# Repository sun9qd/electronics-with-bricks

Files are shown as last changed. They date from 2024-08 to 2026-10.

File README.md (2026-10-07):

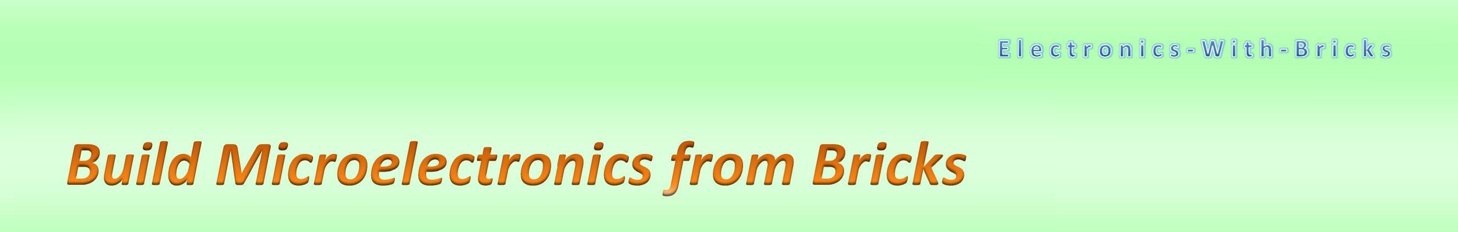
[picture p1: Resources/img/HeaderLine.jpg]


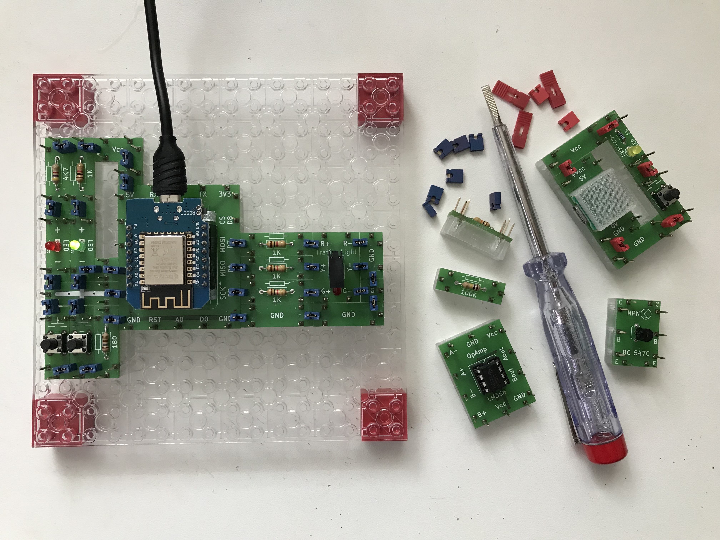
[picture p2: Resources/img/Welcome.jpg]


This project presents an electronic construction kit on 8 mm studded base panel, compatible with standard systems, supporting numerous analog and digital components. From this various analog and digital circuits can be built.

*The latest project built with the construction kit:* A remote-controlled robot car featuring two stacked electronic boards and plenty of space for additional sensor electronics. The picture below shows an assembly with an older brick version.

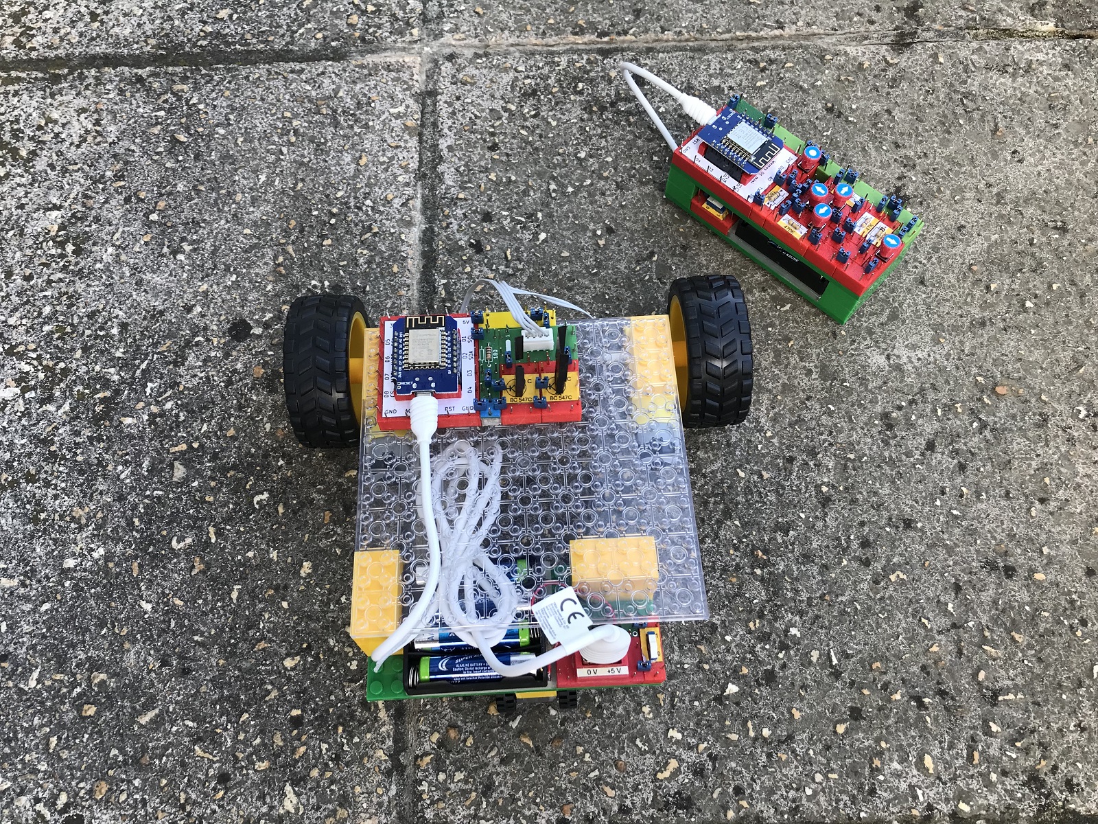
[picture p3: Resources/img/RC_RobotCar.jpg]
Latest project


The kit is intended for:

1. Learning and training
2. Evaluation of electronic components
3. Development of electronic circuits
4. Presentation of technical systems

Compared to using a breadboard, there are some advantages.

1. *Circuit layout  like a photograph of the circuit diagram.*
The wires can be freely routed in two dimensions, whereas on a breadboard, one direction is restricted by the fixed internal wiring. Components and connections are labeled. The tangle of wires is replaced by clearly identifiable jumper connectors.

2. *Robust construction—almost like a manufactured circuit board.*
The components hold firmly to the baseplate, and the jumper connections establish reliable electrical contact. No exposed wires posing a short-circuit risk. 

3. *It’s really fun working with it.*
Finding the best way to lay out the circuit on the base plate. It feels like an amazing, addictive game of skill.

The repository is structured as follows:

- **Applications/** contains a number of experiments built with the kit
- **Bricks/** contains an overview of the available bricks
- **Bundles/** presents several construction kits with varying assortments of building blocks
- **OldApplications/** contains applications with previous version of the kit
- **OldBundles/** contains bundles with previous version of the kit
- **Resources/** contains the resources for reproducing the bricks (STL and Gerber files) and a description how to do that (coming soon)

Note:

LEGO® is a trademark of the LEGO Group. This project is not sponsored, approved or supported by the LEGO Group.

**Warning: The construction kit presented works with electricity. Incorrect use, but also faulty components or circuits, can cause fires and even people and animals can suffer injuries from electric shocks. For this reason, it may only be used by qualified persons. Operation is at your own risk. No liability is assumed for damage resulting from improper assembly or operation.**

The 3D printing templates were created with OpenScad: https://openscad.org/

The board layouts were created with KiCad: https://www.kicad.org/

Some of the description text has been translated with the help of google translator: https://translate.google.com/

Copyright (c) 2024-2026 sun9qd

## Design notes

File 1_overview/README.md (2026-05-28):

# Electronics With Bricks: Sketches

## Laboratory Power Supply

This small circuit provides the voltage of a laboratory power supply to different plugs. The integrated voltmeter displays the current voltage.

The circuit:

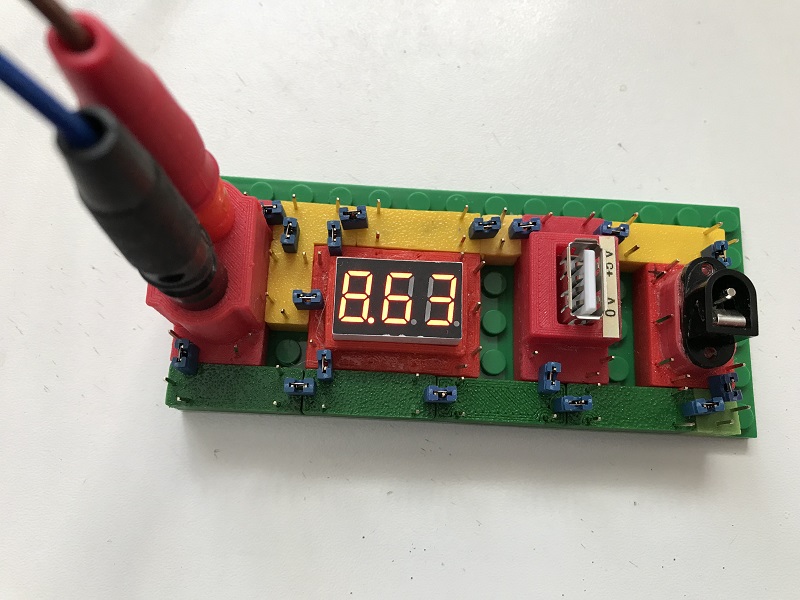
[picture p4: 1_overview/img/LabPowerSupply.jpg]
Lab Power Supply


## Flip-Flop

The most striking thing about the flip-flop circuit or "blinking circuit" are two alternately flashing LEDs that are controlled by two coupled timers. The timing components are a resistor and a capacitor, and there is a transistor as a switch and to drive the LEDs.

The circuit:

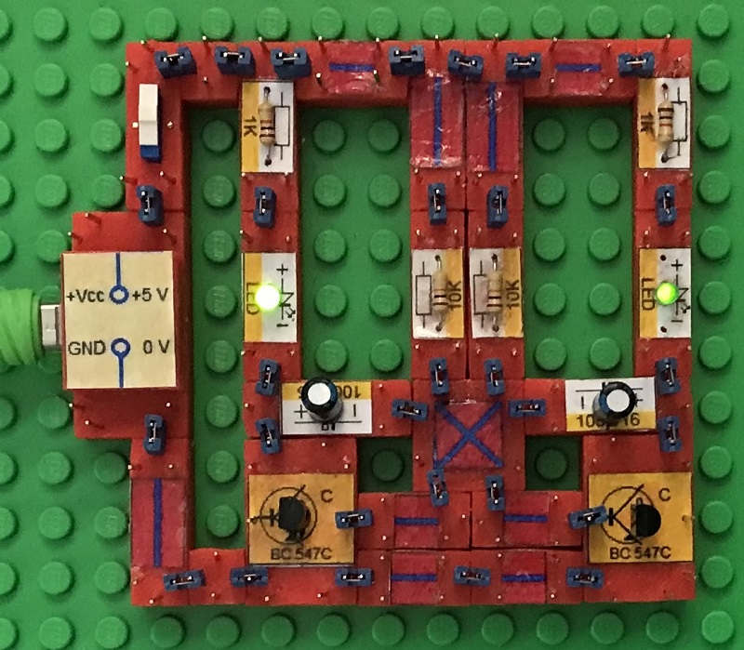
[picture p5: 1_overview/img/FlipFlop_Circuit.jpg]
Flip Flop Circuit


## Analog Water Level Indicator

In this experiment, we build a circuit with which we can measure and display the water level in a water container, e.g. in a water glass or (with a modified sensor) in a rain barrel. The circuit uses analog components in the form of four npn transistors. The water level is displayed using LEDs.

This experiment also shows the use of colored wiring blocks to improve the overview in the circuits. The yellow line blocks are used for the operating voltage, the green ones for the ground line. The latter were not necessary here because the ground line is not switched separately, but is routed via red function blocks.

The circuit:

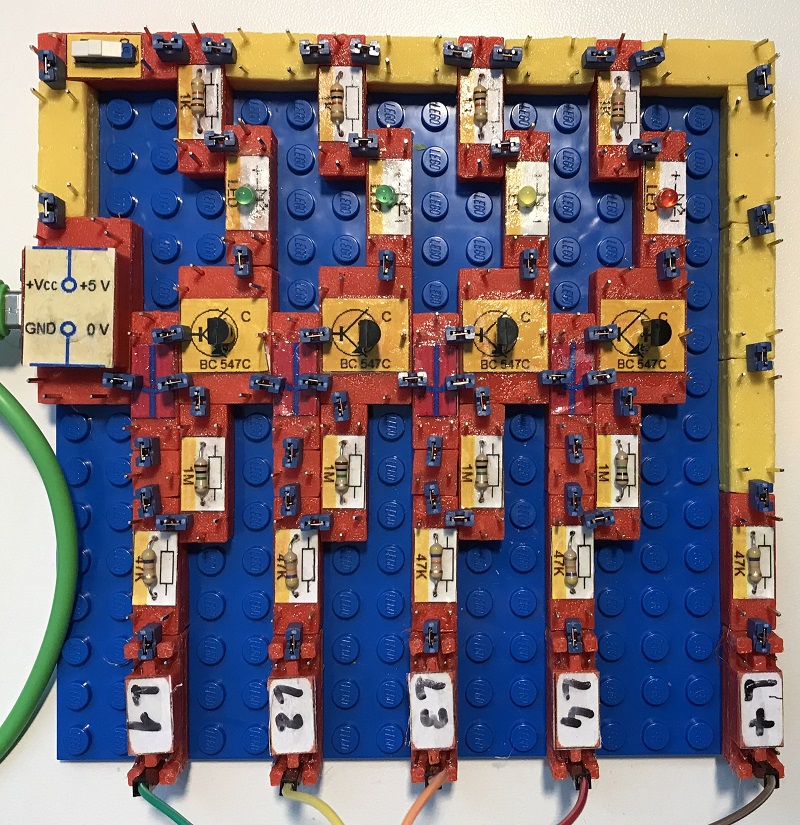
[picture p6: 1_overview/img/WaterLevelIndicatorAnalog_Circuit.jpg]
Water Level Analog Circuit


The entire project, with power supply and sensor:

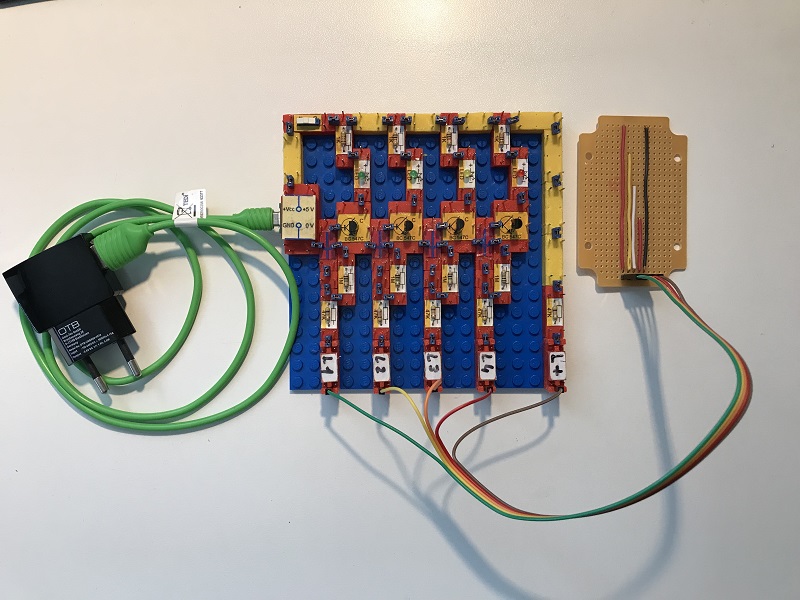
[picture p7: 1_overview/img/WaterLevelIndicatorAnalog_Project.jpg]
Water Level Analog Project


In operation:

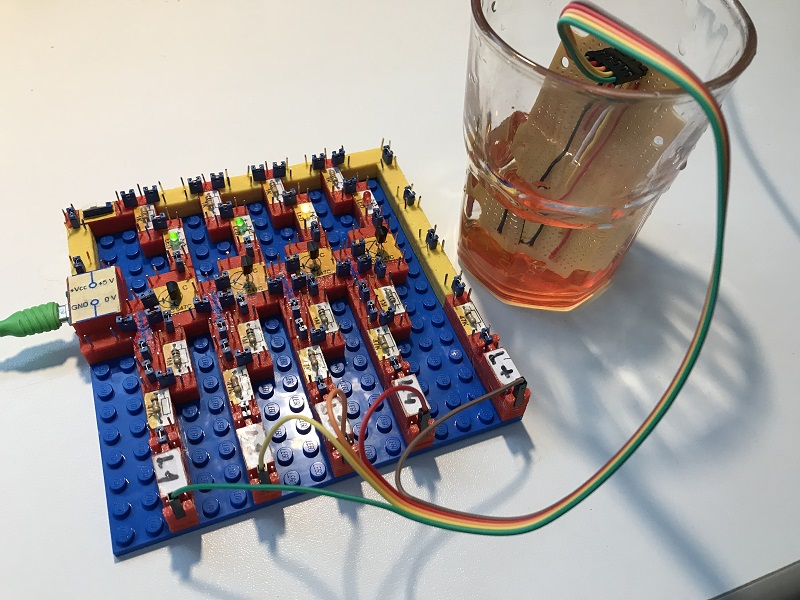
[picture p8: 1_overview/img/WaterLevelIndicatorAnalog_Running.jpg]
Water Level Analog Running


In this experiment, a crossing block is used that makes it possible to cross two lines without them having electrical contact:

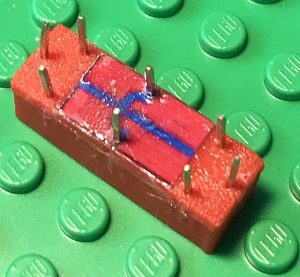
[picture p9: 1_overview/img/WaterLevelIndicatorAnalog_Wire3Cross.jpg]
Crossing block


The crossing block has three pads, with the two outer ones connected to each other inside the block, while the middle one has no connections. In this way, the crossing connection can be switched via the middle pad with its two connectors.

## 7-Segment Display

This experiment is about displaying a single digit, controlled by a Raspberry Pico microcontroller. The microcontroller sends commands via an i2c bus to a port extender chip to set its IO ports so that the desired segments of the display module light up.

The yellow line modules are used for the operating voltage, the green ones for the ground line.

At the top right of the structure you can see a voltmeter module that measures the operating voltage.

The circuit in operation, the controlled display counts up in 1-second steps:

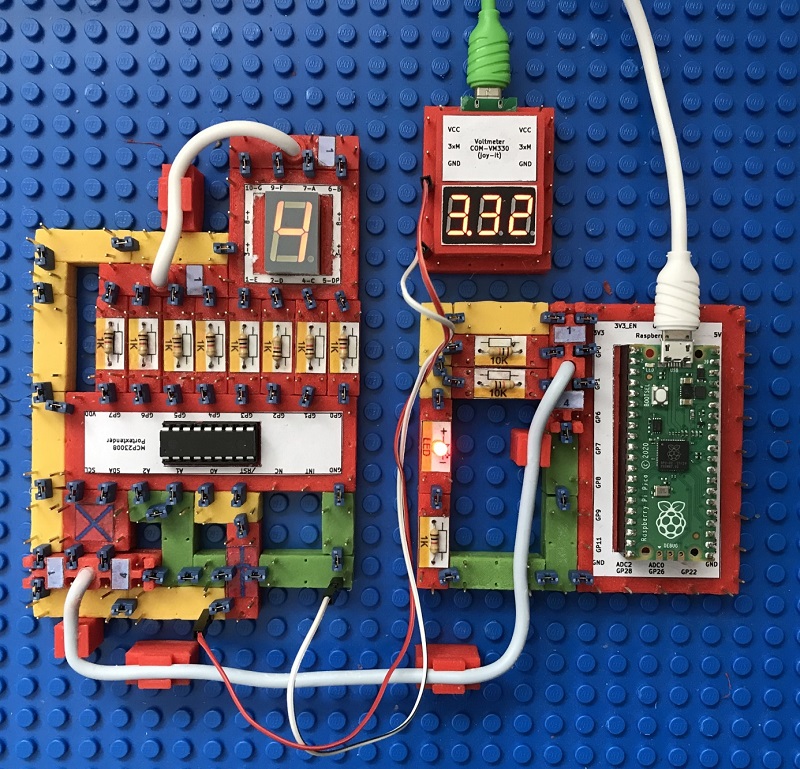
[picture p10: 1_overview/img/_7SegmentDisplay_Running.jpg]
7-Segment Display


In this experiment, a bus line module is used to route Vcc,Ground,SCL and SDA from the microprocessor to the IO extender module. A second of these components redirects the top 4 connections of the display module downwards to the IO extender component.

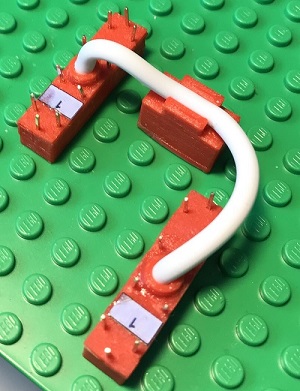
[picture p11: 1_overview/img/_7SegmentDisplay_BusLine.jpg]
7-Segment Busleitung


## Voltmeter

In this experiment we build a voltmeter to measure electrical voltages.

The voltage is measured with an ADC (analog-digital converter) that is built into the D1-Mini microcontroller board.

The measured voltage is displayed on a small graphic display that is connected to the microcontroller via i2c.

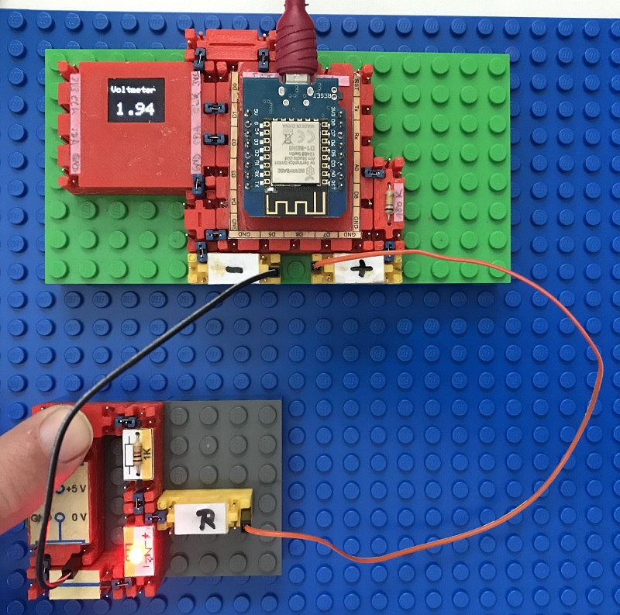
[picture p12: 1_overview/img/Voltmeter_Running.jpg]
Voltmeter


## MP3 Player

In this experiment an integrated MP3 player is used that provides a direct loudspeaker output. The circuit is limited to controlling this component using a series of buttons and connecting a miniature loudspeaker.

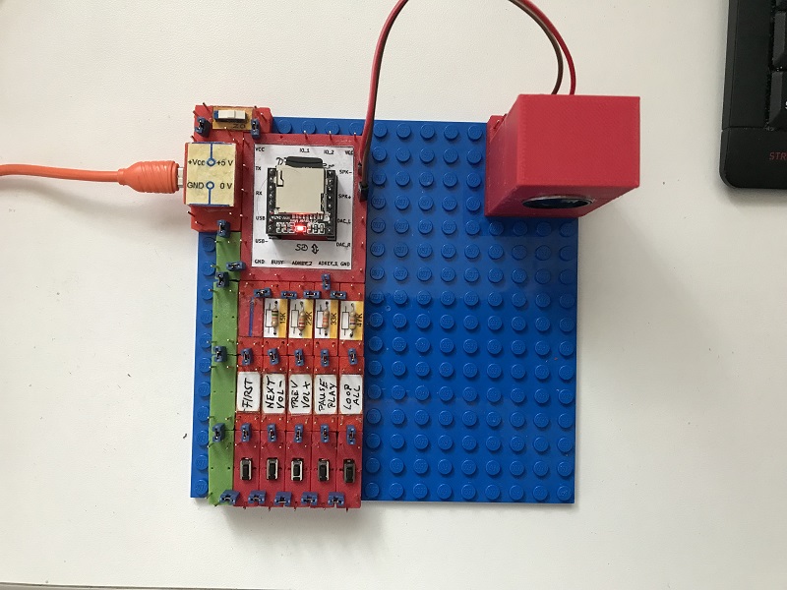
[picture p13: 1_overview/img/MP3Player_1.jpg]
MP3 Player 1


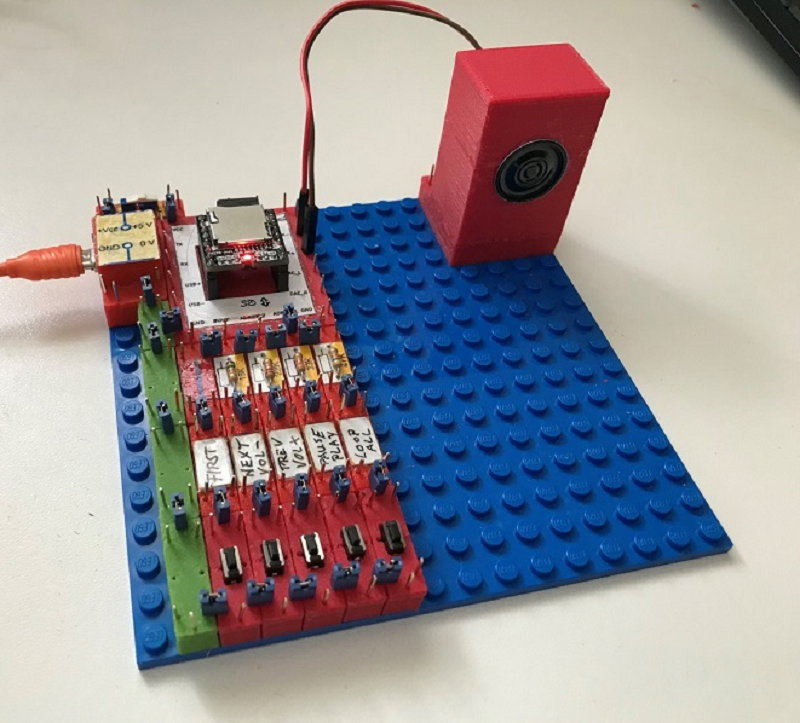
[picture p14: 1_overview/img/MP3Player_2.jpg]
MP3 Player 2


## Power Amplifier

This time I'm trying something more sophisticated. Building a power amplifier with discrete components can cause various problems. For this reason, I'm using a tried and tested and simple circuit that was published under the name "Black Devil" by Elrad magazine many years ago. I found the circuit here:

[https://www.diyaudio.com/community/attachments/black-devil-ii-pdf.146280/](https://www.diyaudio.com/community/attachments/black-devil-ii-pdf.146280/)

The result is impressive. Despite the weak power supply (2 USB chargers PD with 20 volts/30 watts each) and despite the small heat sinks, the amplifier delivers clear sound and powerful bass on a 100 watt bass reflex box. You just have to be careful with the heating of the power amplifier transistors, so don't turn the volume up too high!

As usual, the yellow line components are used for the operating voltage, the green ones for the ground line.

The circuit:

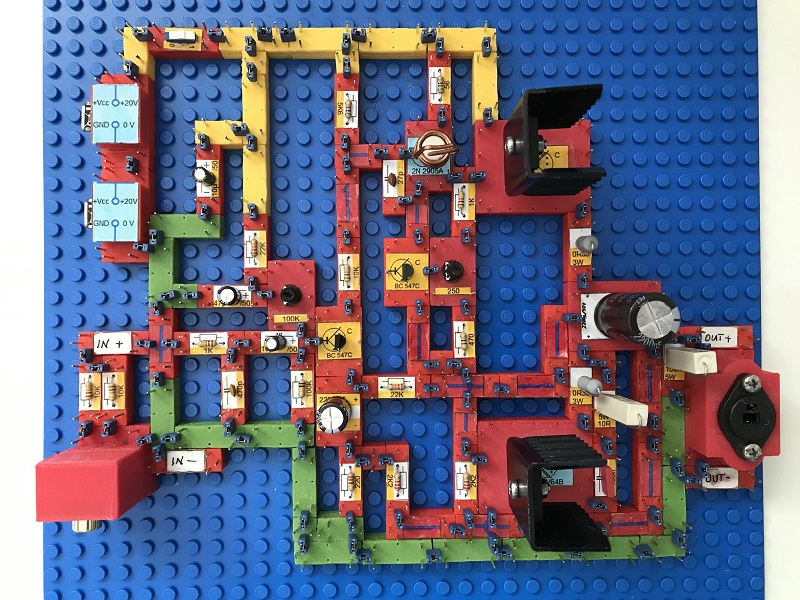
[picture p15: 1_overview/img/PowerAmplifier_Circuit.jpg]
Power Amplifier Running


In operation, the voltmeter measures the center voltage of the amplifier, which should be half the operating voltage:

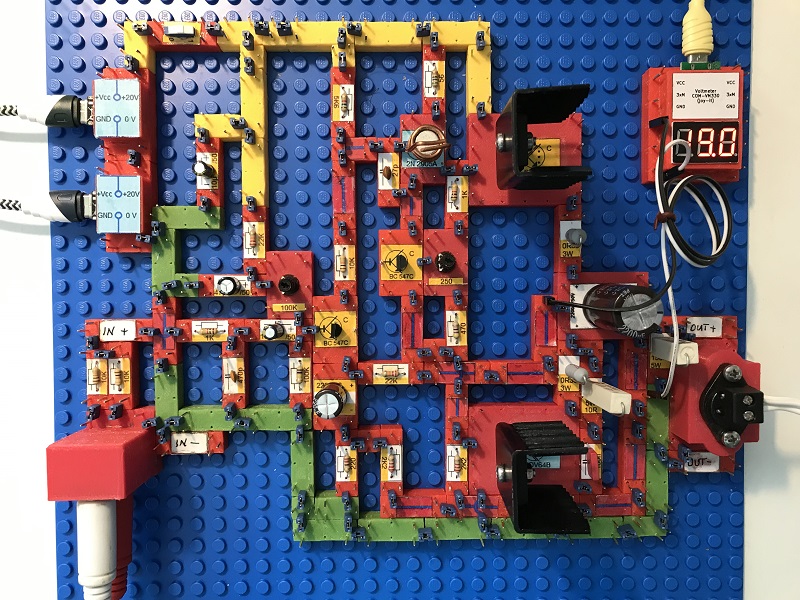
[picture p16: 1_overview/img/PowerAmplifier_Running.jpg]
Power Amplifier Running


## Remote Control

A small remote control for controlling devices via Wi-Fi, built on a 14x6 baseplate. The device connects to a Wi-Fi access point, which is typically provided by a separate construction kit project. Every button press is transmitted, and the remote-controlled project can react in a suitable way to it.

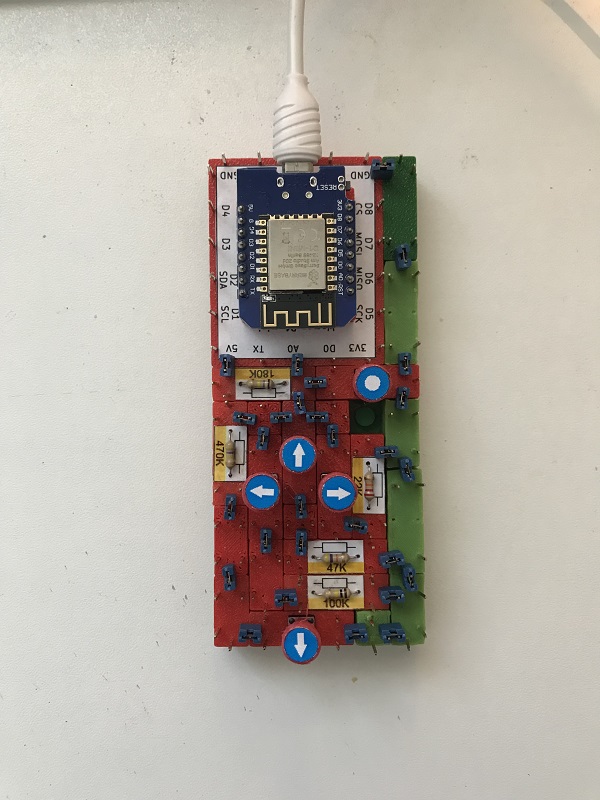
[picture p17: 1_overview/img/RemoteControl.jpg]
Remote Control


As an application example, a remotely controlled variant of the MP3 player project is now available. The up/down keys on the handheld unit control volume in this project, the left/right keys are used to select the song.

The resistor array used to control the player has been replaced by a 100 kΩ SPI digital potentiometer. The function of the buttons is handled by a transistor. The components are driven by a D1 mini microcontroller, which receives its commands via Wi-Fi from the handheld unit of the remote control.

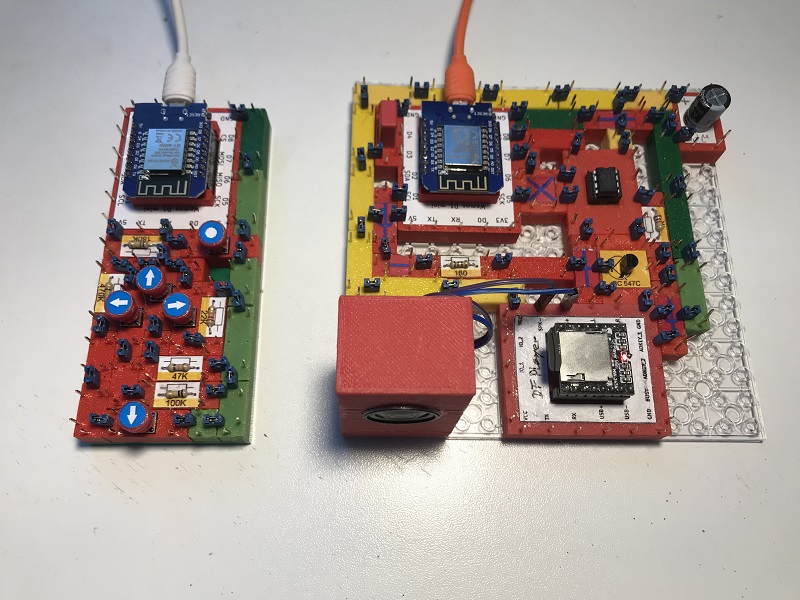
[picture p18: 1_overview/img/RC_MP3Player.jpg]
RC MP3 Player


Copyright (c) 2024-2026 sun9qd

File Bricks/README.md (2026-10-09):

# Electronics-With-Bricks: Brick Overview

The following is an overview of the available building blocks. The list may be incomplete and will be supplemented from time to time.

| | | |
|:---|:---|:---|
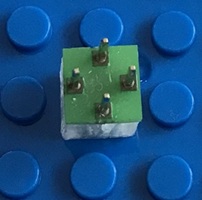
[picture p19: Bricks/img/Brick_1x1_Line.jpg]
Brick_1x1_Line
||**Brick_1x1_Line**:|A piece of wire used to lay signal wires. Available variants: label "G" for ground, label "V" for supply voltage, no label for signals and for the general case.|
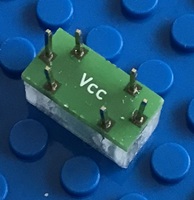
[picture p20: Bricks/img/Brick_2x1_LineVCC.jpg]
Brick_2x1_LineVCC
||**Brick_2x1_LineVCC**:|A piece of wire used to lay VCC (the positive pole of supply voltage). Available variants: label "GND" for ground, label "VCC" for supply voltage, no label for signals and for the general case.|
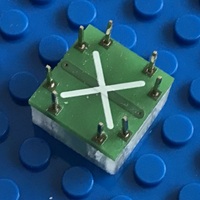
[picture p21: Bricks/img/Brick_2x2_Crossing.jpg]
Brick_2x2_Crossing
||**Brick_2x2_Crossing**:|This brick allows to cross two wires without them having electrical contact.|
|Brick_3x1_Capacitor_ce_50n|**Brick_3x1_Capacitor_ce_50n**:|Ceramic disk capacitor 50 nF, min. 63V.|
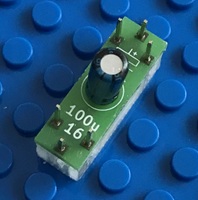
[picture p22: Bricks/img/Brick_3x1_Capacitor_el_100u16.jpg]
Brick_3x1_Capacitor_el_100u16
||**Brick_3x1_Capacitor_el_100u16**:|Electrolytic capacitor 100uF/16V. Available variants of this brick: 22uF/16V, 100uF/16V, 220uF/16V.|
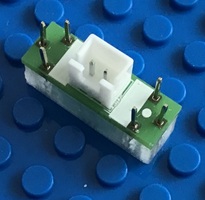
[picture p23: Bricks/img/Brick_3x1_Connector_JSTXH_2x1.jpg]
Brick_3x1_Connector_JSTXH_2x1
||**Brick_3x1_Connector_JSTXH_2x1**:|Standard connector JST XH 2x1.|
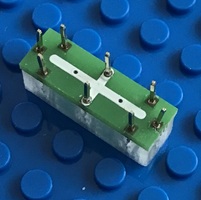
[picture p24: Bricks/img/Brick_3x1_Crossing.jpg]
Brick_3x1_Crossing
||**Brick_3x1_Crossing**:|A second brick for crossing two lines without them having electrical contact to each other.|
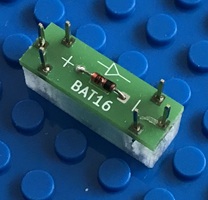
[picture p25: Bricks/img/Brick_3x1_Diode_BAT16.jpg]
Brick_3x1_Diode_BAT16
||**Brick_3x1_Diode_BAT16**:|Universal low power diode BAT16.|
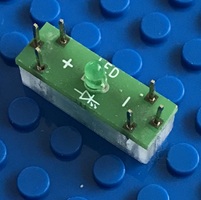
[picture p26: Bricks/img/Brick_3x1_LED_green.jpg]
Brick_3x1_LED_green
||**Brick_3x1_LED_green**:|3mm LED green color. Available variants: 3mm LED red, 3mm LED yellow, 3mm LED green.|
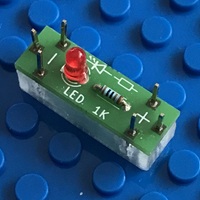
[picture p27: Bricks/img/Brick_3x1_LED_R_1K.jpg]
Brick_3x1_LED_red_R_1K
||**Brick_3x1_LED_red_R_1K**:|3mm LED red color with 1K series resistor. Available variants: 3mm LED red + 1kOhm, 3mm LED yellow + 1kOhm, 3mm LED green + 1kOhm.|
|Brick_3x1_LineGND|**Brick_3x1_LineGND**:|A piece of wire used to lay GND (the negative pole of supply voltage). Available variants: label "GND" for ground, label "VCC" for supply voltage, no label for signals and for the general case.|
|Brick_3x1_Marker|**Brick_3x1_Marker**:|A piece of wire which can be labelled by hand.|
|Brick_3x1_PushButton|**Brick_3x1_PushButton**:|Standard push button.|
|Brick_3x1_Resistor_1K|**Brick_3x1_Resistor_1K**:|Standard resistor 1 kOhm 250 mW. The following resistor Ohm values are available: 1, 10, 22, 47, 100, 180, 220, 470, 1K, 2K2, 4K7, 10K, 22K, 47K, 100K, 180K, 220K, 470K, 1M. |
|Brick_3x1_Switch|**Brick_3x1_Switch**:|A switch to turn an electrical connection on and off.|
|Brick_3x2_Buzzer|**Brick_3x2_Buzzer**:|This brick emits an alarm signal when voltage is applied.|
|Brick_3x2_PerfBoard_5x3|**Brick_3x2_PerfBoard_5x3**:|A perfboard for custom soldering.|
|Brick_3x2_Poti_horz_10K|**Brick_3x2_Poti_horz_10K**:|Potentiometer 10 kOhm with horizontal axis. The following resistor values are available: 1K, 10K, 100K|
|Brick_3x2_Poti_vert_10K|**Brick_3x2_Poti_vert_10K**:|Potentiometer 10 kOhm with vertical axis. The following resistor values are available: 1K, 10K, 100K|
|Brick_3x2_TempSensor_LM235Z|**Brick_3x2_TempSensor_LM235Z**:|Temperature sensor LM235Z.|
|Brick_3x2_TrafficLight|**Brick_3x2_TrafficLight**:|A small traffic light with red, yellow and green LEDs.|
|Brick_3x2_Transistor_npn_BC547C|**Brick_3x2_Transistor_npn_BC547C**:|Universal transistor npn type BC547C.|
|Brick_3x2_Transistor_pnp_BC557C|**Brick_3x2_Transistor_pnp_BC557C**:|Universal transistor pnp type BC557C.|
|Brick_3x3_JackSocket_EBS_35|**Brick_3x3_JackSocket_EBS_35**:|3,5mm jack socket for connecting e.g. a computer headphone output to the circuit.|
|Brick_3x3_Transistor_npn_BD139|**Brick_3x3_Transistor_npn_BD139**:|Medium power npn transistor BD139.|
|Brick_3x3_Transistor_pnp_BD140|**Brick_3x3_Transistor_pnp_BD140**:|Medium power pnp transistor BD140.|
|Brick_4x1_Connector_PinHeader|**Brick_4x1_Connector_PinHeader**:|Standard pin header 4x1 for use with ribbon cables. The following variants are available: 2x1, 3x1, 4x1, 6x1.|
|Brick_4x1_SolderingSupport|**Brick_4x1_SolderingSupport**:|Support tool for soldering the connector pins of the bricks. The following variants are available: 3x1, 4x1, 6x1, 8x1.|
|Brick_4x2_UniversalConnector|**Brick_4x2_UniversalConnector**:|Universal connector 4x1 to be populated by customer.|
|Brick_4x2_USBPowerSupply|**Brick_4x2_USBPowerSupply**:|MicroUSB power supply. This brick contains a MicroUSB socket and loops out the 5V USB supply voltage. This brick can be used to power your circuit from a USB charger.|
|Brick_4x2_USBTypVertical|**Brick_4x2_USBTypVertical**:|USB type A connector. The brick loops out the 5V supply voltage.|
|Brick_4x3_ADC_MCP3002|**Brick_4x3_ADC_MCP3002**:|2 channel SPI analog digital converter.|
|Brick_4x3_AudioAmp_LM386|**Brick_4x3_AudioAmp_LM386**:|Integrated  audio power amplifier for low power applications.|
|Brick_4x3_DAC_MCP4921|**Brick_4x3_DAC_MCP4921**:|1 channel DAC, SPI interface.|
|Brick_4x3_Digipot_100K_MCP4151|**Brick_4x3_Digipot_100K_MCP4151**:|Digital potentiometer MCP4151-104, 100KOhm, SPI interface. The following variant are available: 10K, 100K.|
|Brick_4x3_DIP_8|**Brick_4x3_DIP_8**:|A brick with a DIP-8 socket to be populated by the customer. The "T"-connectors provide a crossing lane below the socket.|
|Brick_4x3_OpAmp_LM358|**Brick_4x3_OpAmp_LM358**:|OpAmp LM358 provides two operational amplifiers.|
|Brick_4x3_Relay_5V_HJR_4102E|**Brick_4x3_Relay_5V_HJR_4102E**:|Relay HJR 4102E, 5V type.|
|Brick_4x3_Speaker_AL_23P|**Brick_4x3_Speaker_AL_23P**:|Miniature 8 Ohm loudspeaker AL-23P.|
|Brick_4x3_Voltmeter|**Brick_4x3_Voltmeter**:|Voltmeter 0-30 Volt.|
|Brick_4x4_7SegmentDigit|**Brick_4x4_7SegmentDigit**:|7 Segment digit, common anode.|
|Brick_4x4_SpeakerBox|**Brick_4x4_SpeakerBox**:|Speaker box with 8 Ohm miniature loudspeaker LSM-20-M/N.|
|Brick_5x5_Display_I2C_128x64_OLED01|**Brick_5x5_Display_I2C_128x64_OLED01**:|I2C display 128x64.|
|Brick_6x4_MotionSensor_HC_SR501|**Brick_6x4_MotionSensor_HC_SR501**:|Motion sensor HC-SR501.|
|Brick_6x5_D1mini|**Brick_6x5_D1mini**:|D1mini microcontroller board with WiFi support.|
|Brick_6x5_DFPlayer|**Brick_6x5_DFPlayer**:|DFPlayer MP3 player.|
|Brick_7x3_DIP_14|**Brick_7x3_DIP_14**:|DIP-14 chip socket to be populated by the customer.|
|Brick_7x3_HexInverter_CD74HCT|**Brick_7x3_HexInverter_CD74HCT**:|HexInverter and schmitt trigger CD74HCT.|
|Brick_8x3_ADC_MCP3008|**Brick_8x3_ADC_MCP3008**:|8-channel ADC MCP3008, SPI interface.|
|Brick_8x3_DIP_16|**Brick_8x3_DIP_16**:|DIP-16 chip socket to be populated by the customer.|
|Brick_8x3_Multiplexer_CD4051B|**Brick_8x3_Multiplexer_CD4051B**:|8-channel multiplexer.|
|Brick_8x8_Breadboard|**Brick_8x8_Breadboard**:|This brick provides a small breadboard. You can set up small circuits or plug in chips or breakout boards (e.g. micro controller boards like D1mini or alike). You can select the breadboard strips you want to use on the brick connectors by connecting them to the female sockets (black colored on two sides of the brick in the picture) using standard breadboard jumper cables.|
|Brick_9x3_DIP_18|**Brick_9x3_DIP_18**:|DIP-18 chip socket to be populated by the customer.|
|Brick_9x3_PortExpander_MCP23008|**Brick_9x3_PortExpander_MCP23008**:|8-channel port expander, I2C interface.|
|Brick_9x5_RaspberryPico|**Brick_9x5_RaspberryPico**:|Microcontroller Raspberry Pico or Raspberry Pico W (the latter with WiFi support).|
|Brick_10x1_WaterSensor|**Brick_10x1_WaterSensor**:|A simple sensor for measuring the water level in a glass of water.|

Copyright (c) 2024-2026 sun9qd

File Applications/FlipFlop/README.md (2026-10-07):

# Electronics With Bricks

## Flip-Flop

The flip-flop circuit provides two alternately flashing LEDs that are controlled by two coupled timers. The timing components are a resistor and a capacitor, and there are two transistors as switches and to drive the LEDs.

The circuit:

Flip Flop Circuit

Copyright (c) 2024-2026 sun9qd

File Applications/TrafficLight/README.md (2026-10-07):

# Electronics With Bricks

## Traffic Light

In this setup, a D1 Mini microprocessor board controls a small traffic light. The user can influence the control system and switch the traffic light between normal operation and service mode using two push-buttons. 

The circuit:

Traffic Light Circuit

In operation:

Traffic Light Operation

Copyright (c) 2024-2026 sun9qd

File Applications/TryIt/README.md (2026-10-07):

# Electronics With Bricks

## Try It!

A simple circuit with an LED and a pushbutton to get to know the modular system principle.

The circuit:

TryIt Circuit

Copyright (c) 2024-2026 sun9qd

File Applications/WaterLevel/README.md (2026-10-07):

# Electronics With Bricks

## Water Level Detector

In this experiment, we build a circuit with which we can measure and display the water level in a water container, e.g. in a water glass or (with a modified sensor) in a rain barrel. The circuit uses analog components in the form of three npn transistors. The water level is displayed using LEDs.

The circuit:

Water Level Circuit

The complete project with power supply and sensor:

Water Level Complete

In operation:

Water Level Operation

Copyright (c) 2024-2026 sun9qd

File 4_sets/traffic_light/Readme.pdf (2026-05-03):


Seite 2 von 8

### Electronics With Bricks

Dieser Baukasten entführt Sie in die spannende Welt der Microelektronik. Sie lernen viele elektronische Bauelemente kennen und konstruieren elektrische Schaltungen.

Copyright (c) 2025

### Sicherheitshinweise

Dieser Baukasten ist kein Spielzeug. Es handelt sich um ein Lernsystem für Erwachsene und für Jugendliche ab 14 Jahre. Je nach persönlicher Vorerfahrung mit Elektrizität ist die Einweisung durch eine fachlich kompetente Person erforderlich.

Falsche Benutzung des Baukastens kann zur Zerstörung von Bauteilen führen, Sachwerte zerstören und Gesundheit und sogar Leben von Tieren und Menschen gefährden durch elektrischen Schlag und Auslösung von Bränden. Bitte seien Sie also vorsichtig, lassen sich gegebenenfalls beraten und lassen Sie keinesfalls Aufbauten dieses Baukastens unbeaufsichtigt am elektrischen Stromnetz!

### ESD

Viele Bricks enthalten hochsensible Halbleiterkomponenten. Weil die Anschlüsse dieser Halbleiter teils direkt auf den Anschlußpins der Bricks liegen, kommt man leicht mit ihnen in Berührung und kann durch elektrostatische Aufladungen des eigenen Körpers die Bauteile zerstören.

Aus diesem Grund muß je nach Kleidung und Umgebung darauf geachtet werden, sich von statischen Aufladungen zu befreien, bevor man Bauteile berührt.

Seite 3 von 8

### Die Bauteile

2 Stück 1 Stück 2 Stück | 3x1 Masseleitung 2x1 Masseleitung 1x1 Masseleitung


1 Stück | 1x1 Signalleitung
1 Stück 1 Stück | 3x1 Plusleitung 1x1 Plusleitung
1 Stück | 3x1 Kreuzung
3 Stück 2 Stück 1 Stück | 3x1 Widerstand 1 kOhm 3x1 Widerstand 4,7 kOhm 3x1 Widerstand 180 Ohm
1 Stück 1 Stück 3 Stück | 3x1 LED rot 3x1 LED grün 3x1 LED gelb


2 Stück | 3x1 Taster
1 Stück | 6x5 D1mini Microcontroller
30 Stück | Jumper Verbinder
1 Stück | 16x16 Noppenplatte als Grundplatte
1 Stück | Micro-USB Kabel
1 Stück | USB Ladegerät
1 Stück | Phasenprüfer


Vorbereitung des Arbeitsplatzes

Konstruktion der Schaltung


Elektrische Verbindung schalten

Alles noch einmal überprüfen

Netzspannung verbinden


Seite 6 von 8

### Schaltplan

Profis entwerfen Schaltungen mit Hilfe elektrischer Schaltpläne. Die Ampel als elektrischer Schaltplan sieht so aus:

Seite 7 von 8

### Die Microcontroller

Das eingesetzte Microcontrollerboard ist vom Typ D1 mini. Der Controller hat ein vorkonfiguriertes Programm, steuert die Ampel und interagiert mit den Tastern und LEDs der Kontrolltafel. Das vorinstallierte C++ Programm kann unter
www.github.com/sun9qd/electronics-with-bricks/ blob/main/assembly_sets/traffic_light/sketch_traffic_light/ sketch_traffic_light.ino
heruntergeladen werden.

Das Programm des Controllers kann geändert werden. Dazu wird der Controller über das USB-Kabel mit einem PC verbunden und mit der Arduino Programmierumgebung neu programmiert.

Der D1 mini hat ein integriertes WLAN Interface. Es ist möglich, das Programm so zu erweitern, daß die Ampel über das Handy gesteuert werden kann.

Seite 8 von 8

Weitere Informationen und Downloads zum Baukastensystem unter

www.github.com/sun9qd/electronics-with-bricks

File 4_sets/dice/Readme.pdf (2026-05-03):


Seite 2 von 8

### Electronics With Bricks

Dieser Baukasten entführt Sie in die spannende Welt der Microelektronik. Sie lernen viele elektronische Bauelemente kennen und konstruieren elektrische Schaltungen.

Copyright (c) 2025

### Sicherheitshinweise

Dieser Baukasten ist kein Spielzeug. Es handelt sich um ein Lernsystem für Erwachsene und für Jugendliche ab 14 Jahre. Je nach persönlicher Vorerfahrung mit Elektrizität ist die Einweisung durch eine fachlich kompetente Person erforderlich.

Falsche Benutzung des Baukastens kann zur Zerstörung von Bauteilen führen, Sachwerte zerstören und Gesundheit und sogar Leben von Tieren und Menschen gefährden durch elektrischen Schlag und Auslösung von Bränden. Bitte seien Sie also vorsichtig, lassen sich gegebenenfalls beraten und lassen Sie keinesfalls Aufbauten dieses Baukastens unbeaufsichtigt am elektrischen Stromnetz!

### ESD

Viele Bricks enthalten hochsensible Halbleiterkomponenten. Weil die Anschlüsse dieser Halbleiter teils direkt auf den Anschlußpins der Bricks liegen, kommt man leicht mit ihnen in Berührung und kann durch elektrostatische Aufladungen des eigenen Körpers die Bauteile zerstören.

Aus diesem Grund muß je nach Kleidung und Umgebung darauf geachtet werden, sich von statischen Aufladungen zu befreien, bevor man Bauteile berührt.

Seite 3 von 8

### Die Bauteile

1 Stück 1 Stück | 3x1 Masseleitung 1x1 Masseleitung
6 Stück 3 Stück 2 Stück | 3x1 Signalleitung 2x1 Signalleitung 2x1 Signalleitung
4 Stück 1 Stück 1 Stück | 3x1 Plusleitung 2x1 Plusleitung 1x1 Plusleitung


2 Stück | 3x1 Kreuzung
8 Stück 1 Stück | 3x1 Widerstand 1 kOhm 3x1 Widerstand 100 kOhm
1 Stück | 3x1 Taster
1 Stück | 6x5 D1mini Microcontroller
1 Stück | 9x3 MCP23008 IOExpander
1 Stück | 4x4 7Segment Display
47 Stück | Jumper Verbinder
1 Stück | 16x16 Noppenplatte als Grundplatte
1 Stück | Micro-USB Kabel
1 Stück | USB Ladegerät
1 Stück | Phasenprüfer


Vorbereitung des Arbeitsplatzes

Konstruktion der Schaltung


Elektrische Verbindung schalten

Alles noch einmal überprüfen

Netzspannung verbinden


Seite 6 von 8

### Schaltplan

Profis entwerfen Schaltungen mit Hilfe elektrischer Schaltpläne. Der Würfel als elektrischer Schaltplan sieht so aus:

Die Anschlüsse A0, A1, A2 des MCP23008 müssen nicht explizit verschaltet werden. Sie sind innerhalb des Bricks über 10kOhm Pulldown-Widerständen mit Ground verbunden.

Der Anschluß RESET/ des MCP23008 muß ebenfalls nicht explizit verschaltet werden. Er ist innerhalb des Bricks über einem 10kOhm Pullup-Widerstand mit VDD (Versorgungsspannung) verbunden. Auf diese Weise ist der Chip immer im Normalbetrieb.

Seite 7 von 8

### Die Microcontroller

Das eingesetzte Microcontrollerboard ist vom Typ D1 mini. Der Controller hat ein vorkonfiguriertes Programm, reagiert auf das Drücken des Tasters und zeigt eine Zufallszahl auf der 7-Segmentanzeige an. Das vorinstallierte C++ Programm kann unter
www.github.com/sun9qd/electronics-with-bricks/ blob/main/assembly_sets/dice/sketch_dice/
sketch_dice.ino
heruntergeladen werden.

Das Programm des Controllers kann geändert werden. Dazu wird der Controller über das USB-Kabel mit einem PC verbunden und mit der Arduino Programmierumgebung neu programmiert.

Der D1 mini hat ein integriertes WLAN Interface. Es ist möglich, das Programm so zu erweitern, daß die 7-Segmentanzeige über das Handy gesteuert werden kann.

Seite 8 von 8

Weitere Informationen und Downloads zum Baukastensystem unter

www.github.com/sun9qd/electronics-with-bricks

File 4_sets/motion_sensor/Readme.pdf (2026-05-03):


Seite 2 von 8

## Electronics With Bricks

Kennen Sie das auch? Unerwünschte Besucher könnten unerkannt Ihre privaten Räume betreten. Da wäre doch eine Überwachung des Eingangsbereichs sehr praktisch!

Dieser Baukasten entführt Sie in die spannende Welt der Microelektronik. Sie lernen viele elektronische Bauelemente kennen und konstruieren elektrische Schaltungen.

Copyright (c) 2025

## Sicherheitshinweise

Dieser Baukasten ist kein Spielzeug. Es handelt sich um ein Lernsystem für Erwachsene und für Jugendliche ab 14 Jahre. Je nach persönlicher Vorerfahrung mit Elektrizität ist die Einweisung durch eine fachlich kompetente Person erforderlich.

Falsche Benutzung des Baukastens kann zur Zerstörung von Bauteilen führen, Sachwerte zerstören und Gesundheit und sogar Leben von Tieren und Menschen gefährden durch elektrischen Schlag und Auslösung von Bränden. Bitte seien Sie also vorsichtig, lassen sich gegebenenfalls beraten und lassen Sie keinesfalls Aufbauten dieses Baukastens unbeaufsichtigt am elektrischen Stromnetz!

## ESD

Viele Bricks enthalten hochsensible Halbleiterkomponenten. Weil die Anschlüsse dieser Halbleiter teils direkt auf den Anschlußpins der Bricks liegen, kommt man leicht mit ihnen in Berührung und kann durch elektrostatische Aufladungen des eigenen Körpers die Bauteile zerstören.

Aus diesem Grund muß je nach Kleidung und Umgebung darauf geachtet werden, sich von statischen Aufladungen zu befreien, bevor man Bauteile berührt.

Seite 3 von 8

## Die Bauteile


1 Stück 1 Stück | brick_2x1_GroundLine brick_1x1_GroundLine
1 Stück | brick_2x1_SignalLine
1 Stück | brick_1x1_VccLine
1 Stück | brick_3x1_Crossing
1 Stück | brick_3x1_Resistor_1k
1 Stück | 3x1_LED_5mm_red
1 Stück | brick_6x4_MotionSensor
1 Stück | 6x5 D1mini Microcontroller
12 Stück | Jumper Verbinder
1 Stück | 14x6 Noppenplatte als Grundplatte
1 Stück | Micro-USB Kabel
1 Stück | USB Ladegerät
1 Stück | Phasenprüfer


Vorbereitung des Arbeitsplatzes

Konstruktion der Schaltung


Elektrische Verbindung schalten

Alles noch einmal überprüfen

Netzspannung verbinden

So funktioniert's

Seite 6 von 8

Nach der Konfiguration (s.u.) kann man sich von einem Computer oder einem Handy aus über WLAN mit dem Microcontroller verbinden und eine Alarmseite http://<ip-Adresse>/run anzeigen:

Bei erkannter Bewegung ändert sich die Darstellung zu

Konfiguration des Bewegungssensors

Seite 7 von 8

Für die volle Funktionalität sind noch einige Konfigurationseinstellungen zu machen:

- Ohne Konfiguration öffnet der D1 mini Microcontroller einen eigenen WLAN Accesspoint. Sie können sich mit dem Mikrocontroller verbinden, wenn Sie einen Computer mit dem WLAN-Netz "Electronics-With-Bricks" verbinden. Das zugehörige WLAN-Passwort ist "Electronics-With-Bricks". Der Microcontroller ist in diesem Netztwerk erreichbar mit der IP-Adresse 192.168.4.1. Bitte immer das Protokoll http angeben, weil das Default-Protokoll https vieler Browser am D1 mini nicht verfügbar ist. Also die Adresse http://192.168.4.1 verwenden.
- Die folgenden Seiten sind verfügbar:
o 192/168.4.1: Name und Version des installierten Programms
o 192/168.4.1/config: WLAN-Konfiguration des D1 mini
o 192/168.4.1/run: Anzeige von entdeckten Bewegungen am Display
- Unter 192/168.4.1/config können die folgenden Parameter eingetragen werden, um den D1 mini im normalen Haus-WLAN erreichen zu können.
o Hostname: Ein symbolischer Name (Sie können dann http://<Name> anstelle der IP Adresse verwenden
o Netzwerk: Der Name des Haus-WLAN-Netzes
o Password: Das Passwort für den Zugang in das Netz (oft am Gehäuseboden des Haus-WLAN-Routers zu finden)


Bemerkung: Die Benutzung im Haus-WLAN ist derzeit nur bei DHCP-Netzen möglich. Für eine Benutzung in Netzen mit fester Vergabe von IP-Adressen muß das C++ Programm (s.u.) angepaßt werden.

Seite 8 von 8

- Anschließend abmelden vom WLAN Netz "Electronics-With-Bricks" und wieder ganz normal mit dem Haus-WLAN verbinden.
- Der D1 mini muß jetzt neu gestartet werden, z.B. indem das USB-Ladegerät aus der Steckdose gezogen und anschließend wieder eingesteckt wird. Jetzt sollte der Bewegungssensor erreicht werden können unter http://<Name>/run

## Die Microcontroller

Das eingesetzte Microcontrollerboard ist vom Typ D1 mini. Der Controller hat ein vorkonfiguriertes Programm, liest den Zustand des Bewegungssensors und alarmiert den Benutzer über WLAN bei erkannten Bewegungen in der Umgebung. Das vorinstallierte C++ Programm kann unter www.github.com/sun9qd/electronics-with-bricks/ blob/main/assembly_sets/motion_sensor/sketch_motion_sensor/ sketch_motion_sensor.ino
heruntergeladen werden.

Weitere Informationen und Downloads zum Baukastensystem unter

www.github.com/sun9qd/electronics-with-bricks

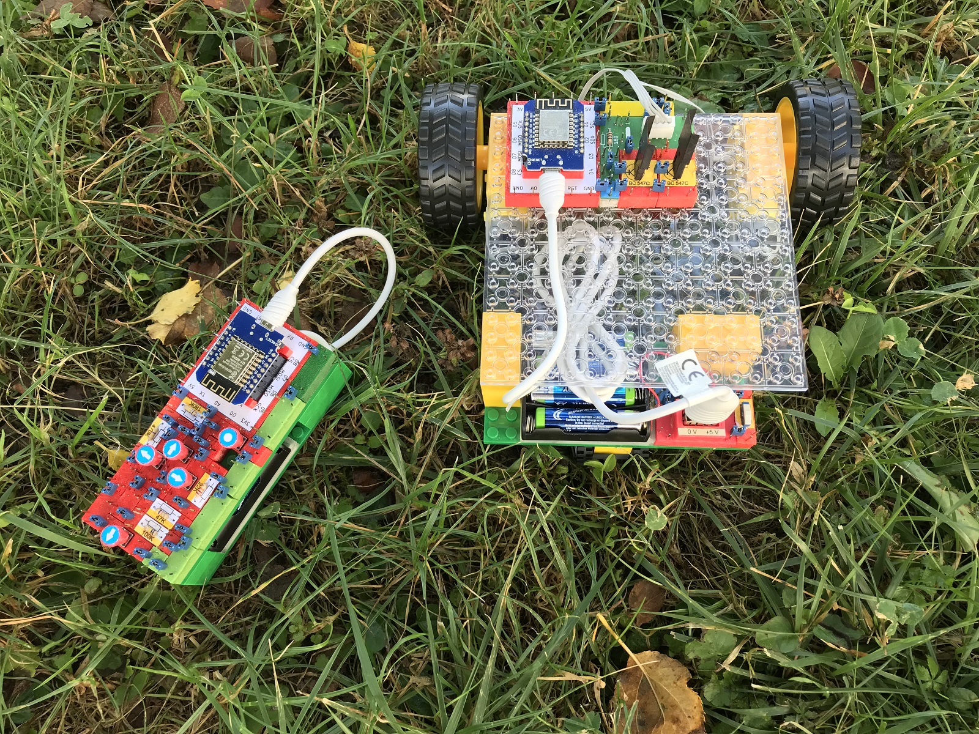
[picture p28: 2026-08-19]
1_overview/img/RC_RobotCar.jpg

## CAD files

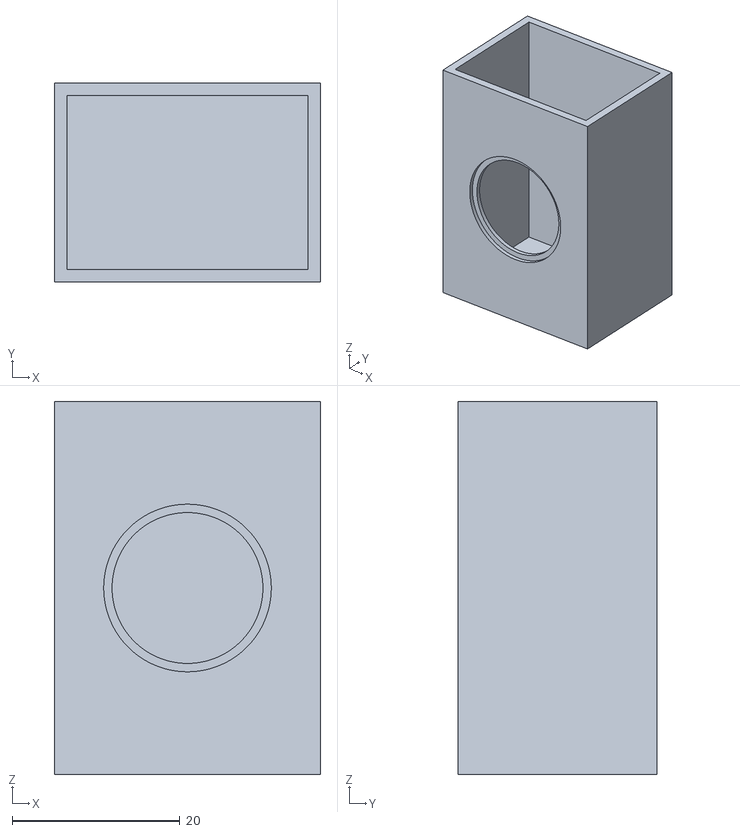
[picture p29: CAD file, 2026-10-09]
Resources/stl/body_speakerBox.stl
31.8 x 23.8 x 44.5

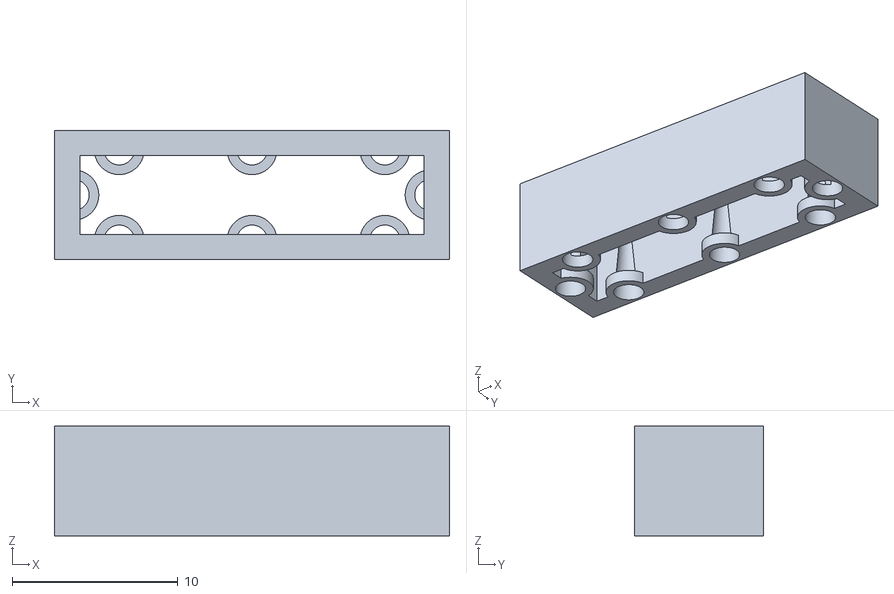
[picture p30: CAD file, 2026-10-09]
Resources/stl/body_3x1.stl
23.8 x 7.80 x 6.60

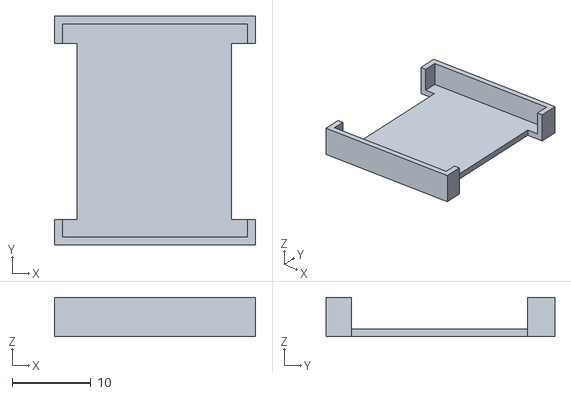
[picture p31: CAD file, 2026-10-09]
Resources/stl/body_D1mini_top.stl
25.5 x 29.0 x 5.00

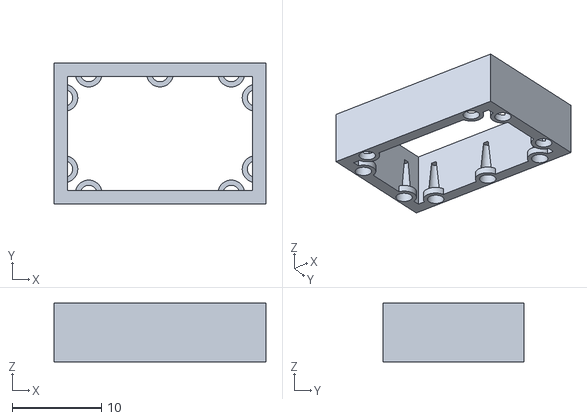
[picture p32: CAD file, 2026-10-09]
Resources/stl/body_3x2_lrt.stl
23.8 x 15.8 x 6.60

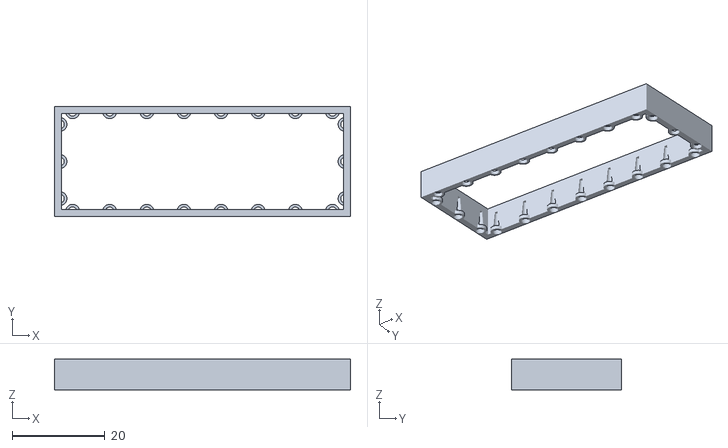
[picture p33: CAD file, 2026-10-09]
Resources/stl/body_8x3.stl
63.8 x 23.8 x 6.60

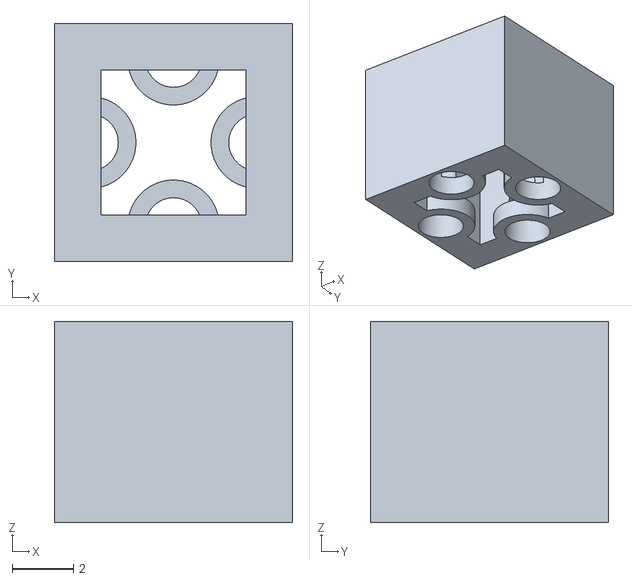
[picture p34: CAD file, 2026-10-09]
Resources/stl/body_1x1.stl
7.80 x 7.80 x 6.60

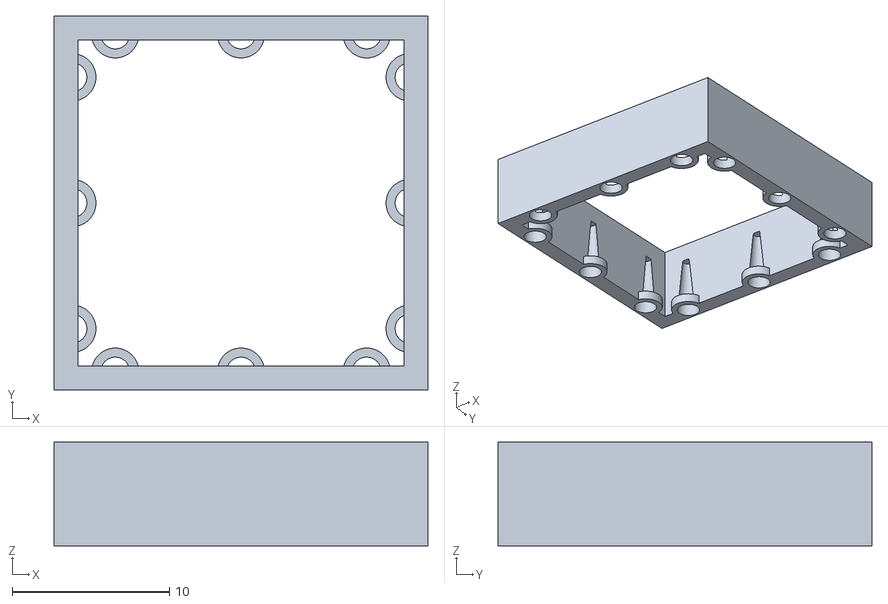
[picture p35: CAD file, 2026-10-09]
Resources/stl/body_3x3.stl
23.8 x 23.8 x 6.60

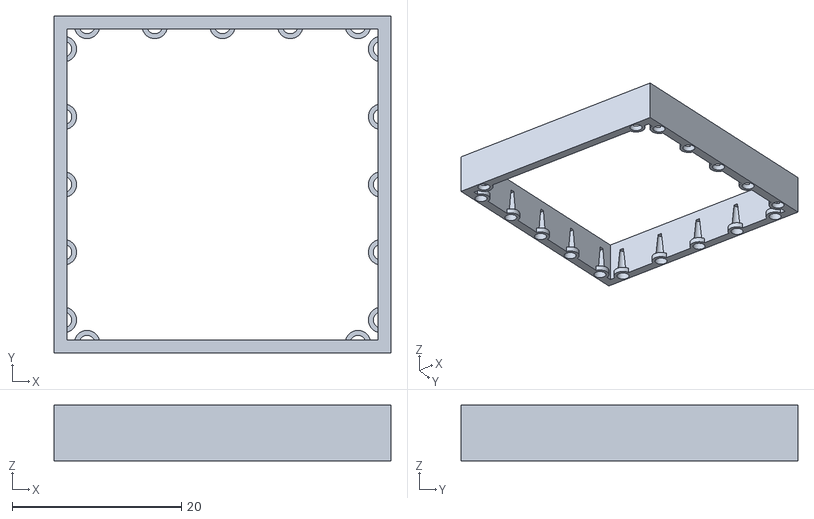
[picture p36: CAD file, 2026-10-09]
Resources/stl/body_5x5_lrt.stl
39.8 x 39.8 x 6.60

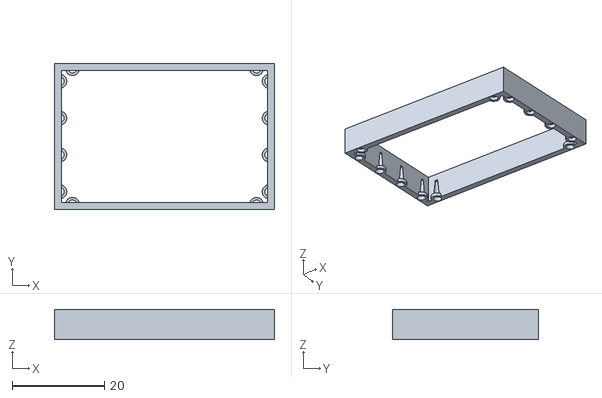
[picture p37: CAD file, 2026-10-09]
Resources/stl/body_6x4_lr.stl
47.8 x 31.8 x 6.60

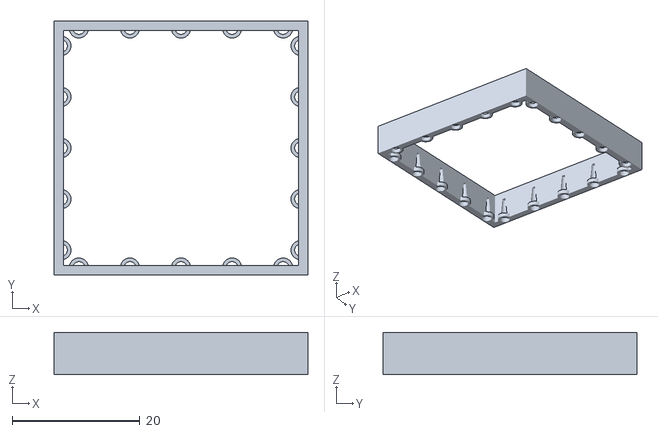
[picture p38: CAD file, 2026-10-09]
Resources/stl/body_5x5.stl
39.8 x 39.8 x 6.60

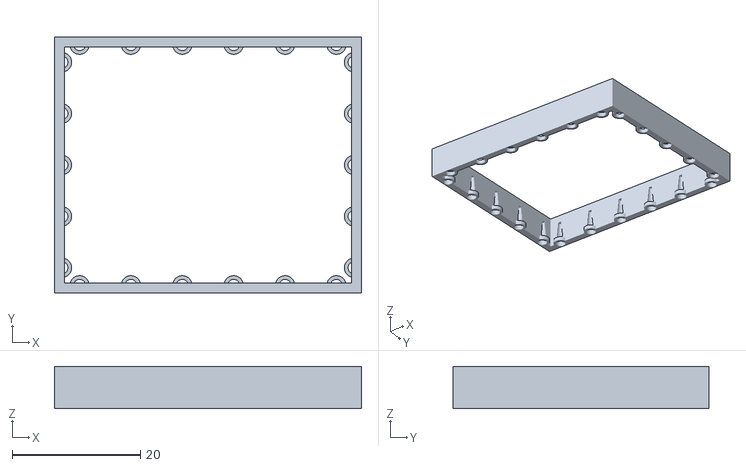
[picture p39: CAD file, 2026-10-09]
Resources/stl/body_6x5.stl
47.8 x 39.8 x 6.60

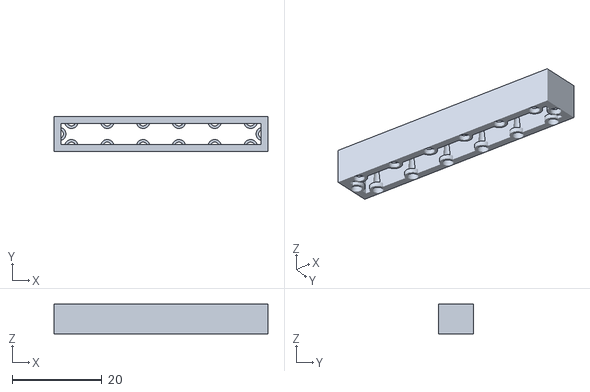
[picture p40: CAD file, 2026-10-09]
Resources/stl/body_6x1.stl
47.8 x 7.80 x 6.60

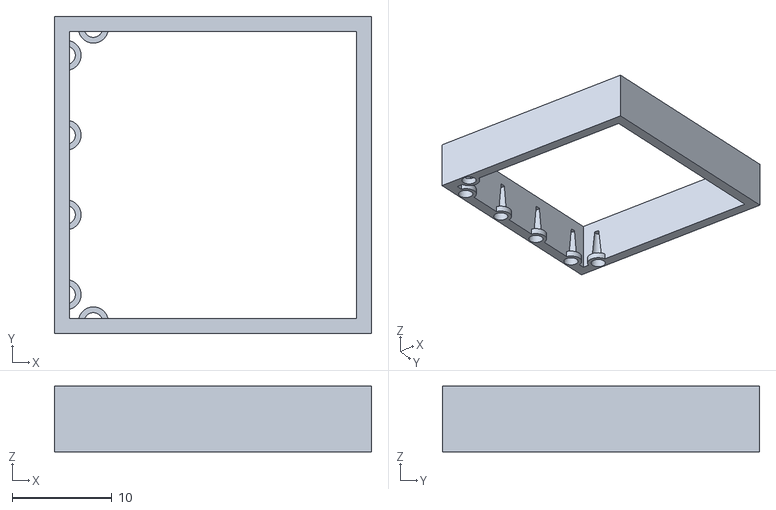
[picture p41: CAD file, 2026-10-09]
Resources/stl/body_4x4_l.stl
31.8 x 31.8 x 6.60

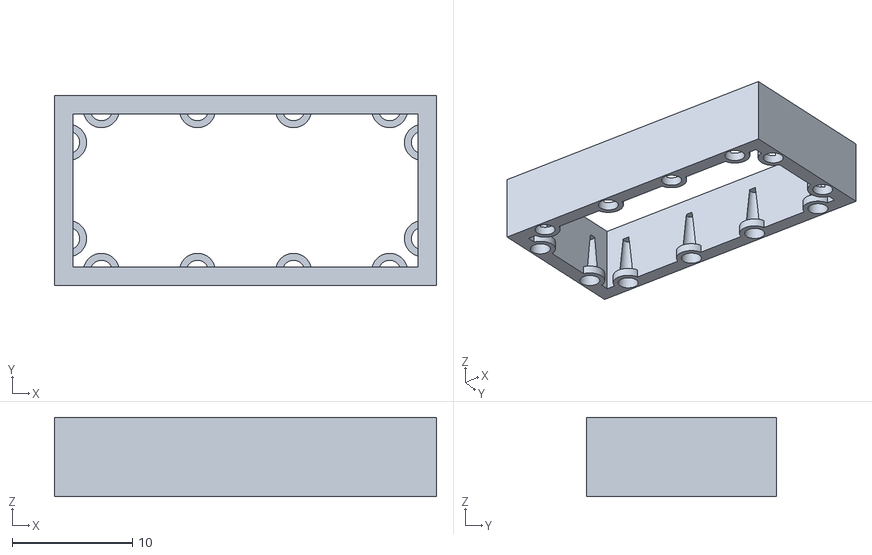
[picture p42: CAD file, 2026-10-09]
Resources/stl/body_4x2.stl
31.8 x 15.8 x 6.60

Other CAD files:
Resources/stl/body_3x2.stl
Resources/stl/body_3x1_pushbutton.stl
Resources/stl/body_3x1_lr.stl
Resources/stl/body_3x2_fan.stl
Resources/stl/body_2x1.stl
Resources/stl/body_2x2.stl
Resources/stl/body_3x1_solderingSupport.stl
Resources/stl/body_3x2_lr.stl
Resources/stl/body_3x3_lrt.stl
Resources/stl/body_4x1.stl
Resources/stl/body_4x1_solderingSupport.stl
Resources/stl/body_4x2_lr.stl
Resources/stl/body_4x3.stl
Resources/stl/body_4x3_lr.stl
Resources/stl/body_4x4.stl
Resources/stl/body_6x1_solderingSupport.stl
Resources/stl/body_6x4.stl
Resources/stl/body_6x4_GroundPlate.stl
Resources/stl/body_7x3.stl
Resources/stl/body_8x1_solderingSupport.stl
Resources/stl/body_8x8.stl
Resources/stl/body_9x3.stl
Resources/stl/body_CableMarker.stl
Resources/stl/body_DFPlayer_top.stl
Resources/stl/body_Voltmeter_top.stl
Resources/stl/body_microUSB_top.stl
Resources/stl/body_pushbutton_top.stl
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

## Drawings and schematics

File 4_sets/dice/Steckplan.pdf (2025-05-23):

# Steckplan elektronischer Würfel

## D1 mini

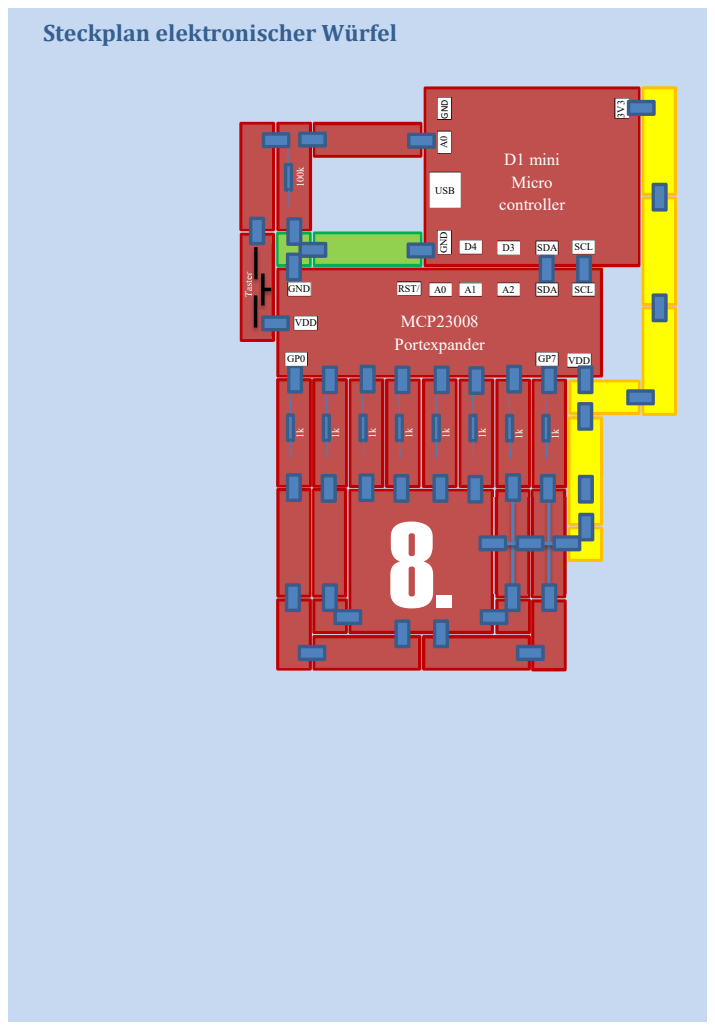
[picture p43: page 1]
Micro; controller ¹⁰⁰k; GND; 8.GND A⁰; SDA; SCL MCP23008; Portexpander; VDD 1k; RST/; SCL; VDD; USB Taster

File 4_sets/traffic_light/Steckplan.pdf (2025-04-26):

# Steckplan

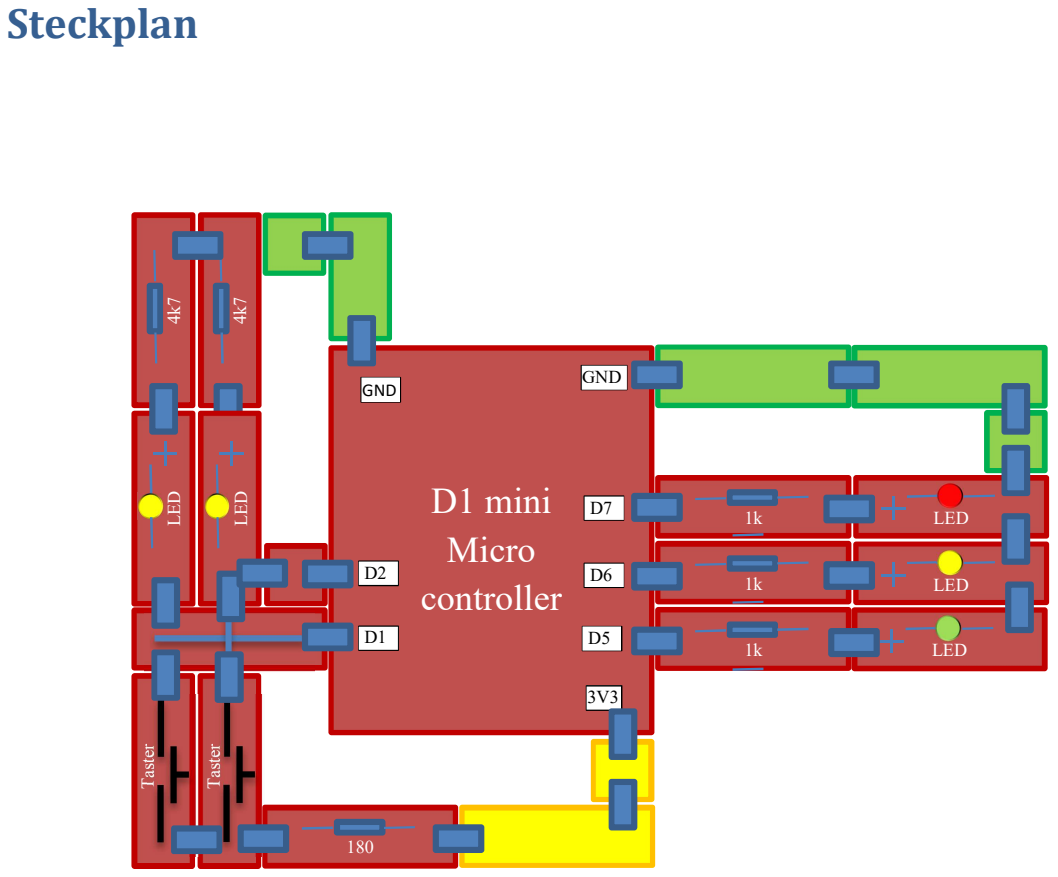
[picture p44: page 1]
D1 mini Micro controller; GND; LED LED ⁴k7; 4k7 Taster; LED; LED Taster

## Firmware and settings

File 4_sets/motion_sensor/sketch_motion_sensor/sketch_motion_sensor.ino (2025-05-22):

// Todo
//
// x Allgemeine ewb Basisklasse mit xml type/revision über wlan
// Umstellen auf eigenen WLAN Accesspoint, Passwort per Web
// x Fix: Mehrere Clients bedienen, lange Aktivzeit, damit jeder es mitbekommt
// Umbenennen MoveDetect -> MotionDetector ?
// Schnellere Reaktion: Polling -> WebSocket ?


#include <ESP8266WiFi.h>
#include <ESP8266WebServer.h>
#include <LittleFS.h>

#define VERSION         "1.0"



// *******************************************************************************
// CElectronics
// Base class for Electronics-With-Bricks assembly sets
// (to be moved to a separate file)
// *******************************************************************************

class CElectronics
{
public:
  CElectronics( const char* szAssemblySet, const char* szVersion );

  virtual void setup();
  virtual void loop();

  static void webpageNotFound();
  static void webpageInfo();
  static void webpageConfig();

public:
  static ESP8266WebServer m_server;
  static String m_strAssemblySet;
  static String m_strVersion;

  static String m_strName;
  static String m_strSSID;
  static String m_strPassword;

protected:
  String m_strAccessPointName;
};

ESP8266WebServer CElectronics::m_server(80);
String CElectronics::m_strAssemblySet;
String CElectronics::m_strVersion;
String CElectronics::m_strName = "motion";
String CElectronics::m_strSSID;
String CElectronics::m_strPassword;


CElectronics::CElectronics( const char* szAssemblySet, const char* szVersion )
{
  m_strAssemblySet = szAssemblySet;
  m_strVersion = szVersion;

  m_strAccessPointName = "Electronics-With-Bricks";
}

void CElectronics::setup()
{
  // Store my parameters as one file per parameter on LittleFS
  File file = LittleFS.open( "/name.par", "r" );
  if( file ) { m_strName = file.readString(); file.close(); }
  file = LittleFS.open( "/ssid.par", "r" );
  if( file ) { m_strSSID = file.readString(); file.close(); }
  file = LittleFS.open( "/password.par", "r" );
  if( file ) { m_strPassword = file.readString(); file.close(); }

  Serial.printf( "Name = \"%s\"\n", m_strName.c_str() );
  Serial.printf( "SSID = \"%s\"\n", m_strSSID.c_str() );
  // - not showing password - Serial.printf( "Password = \"%s\"\n", m_strPassword.c_str() );

  WiFi.disconnect() ;
  WiFi.softAPdisconnect( true );
  WiFi.begin( m_strSSID, m_strPassword ); //Initialisieren der Wifi Verbindung.

  if( WiFi.waitForConnectResult() == WL_CONNECTED )
  {
    Serial.printf("Server address: http://");
    Serial.printf( "WLAN connected: IP = %s\n", WiFi.localIP().toString().c_str() );
  }
  else
  {
    WiFi.softAP ( m_strAccessPointName, m_strAccessPointName ) ;  // Configure as wifi access point
    delay ( 500 ) ;
    Serial.printf ( "Access point started: IP = 192.168.4.1\n" ) ;            // Address if AP
  }

  if( m_strName.length() > 0 )
    WiFi.hostname( m_strName.c_str() );

  m_server.begin(); // Starten des Servers.
  m_server.onNotFound( webpageNotFound);
  m_server.on( "/info", webpageInfo );
  m_server.on( "/config", webpageConfig );
  Serial.println("Server gestartet");
}

void CElectronics::loop()
{
  m_server.handleClient();
}

void CElectronics::webpageNotFound()
{ 
  Serial.println( "-> webpageNotFound()" );
  m_server.send(404, "text/plain", "404: Not found"); 
}

void CElectronics::webpageInfo()
{
  String content = "";
  content += "<!DOCTYPE HTML>";
  content += "<html>"; 

  content += "<head>"; 
  content += "<style>"; 
  content += ".wrapper {max-width:90%;margin:0 auto;text-align:left;}"; 
  content += ".btn {margin:15px;}";   
  content += "</style>";
  content += "</head>"; 

  content += "<body>"; 
  content += "<div class='wrapper'>"; 
  content += "<h2>Electronics-With-Bricks</h2>"; 
  content += "<br>Assembly Set = " + m_strAssemblySet; 
  content += "<br>Version = " + m_strVersion + ""; 
  content += "</div>"; 
  content += "</body>"; 

   CElectronics::m_server.send( 200, "text/html", content);
}

void CElectronics::webpageConfig()
{
  int numberOfArgs = m_server.args();
  for( int i = 0; i < numberOfArgs; i++ )
  {
    String strName = m_server.argName(i);
    String strValue = m_server.arg(i);
    //int nValue = atoi(strValue.c_str());

    if( strName == "ssid" )
    {
      m_strSSID = strValue;
      Serial.printf( "Config: ssid = %s\n", m_strSSID.c_str() );
//      Serial.println( m_strSSID );
      File file = LittleFS.open( "/ssid.par", "w" );
      if( file ) { Serial.println("write to file"); file.write( m_strSSID.c_str() ); delay(1); file.close(); }
    }
    else if( strName == "password" )
    {
      m_strPassword = strValue;
      Serial.printf( "Config: password = %s\n", m_strPassword.c_str() );
      File file = LittleFS.open( "/password.par", "w" );
      if( file ) { Serial.println("write to file"); file.write( m_strPassword.c_str() ); delay(1); file.close(); }
    }
    else if( strName == "name" )
    {
      m_strName = strValue;
      Serial.printf( "Config: name = %s\n", m_strName.c_str() );
      File file = LittleFS.open( "/name.par", "w" );
      if( file ) { Serial.println("write to file"); file.write( m_strName.c_str() ); delay(1); file.close(); }
    }
  }


  String content = "";
  content += "<!DOCTYPE HTML>";
  content += "<html>"; 

  content += "<head>"; 
  content += "<style>"; 
  content += ".wrapper {max-width:90%;margin:0 auto;text-align:left;}"; 
  content += ".btn {margin:15px;}";   
  content += "</style>";
  content += "</head>"; 

  content += "<body>"; 
  content += "<div class='wrapper'>"; 
  content += "<h2>Electronics-With-Bricks</h2>"; 
  content += "<br>Assembly Set = " + m_strAssemblySet; 
  content += "<br>Version = " + m_strVersion + ""; 

// Form for config of SSID and PASSWORD
  content += "<form action=\"/config\">";

  content += "<br><label for=\"name\">Hostname: </label>";
  content += String("") + "<input type=\"text\" id=\"name\" name=\"name\" value=\"" + m_strName.c_str() + "\"><br>";

  content += "<br><label for=\"ssid\">Netzwerk: </label>";
  content += String("") + "<input type=\"text\" id=\"ssid\" name=\"ssid\" value=\"" + m_strSSID.c_str() + "\"><br>";

  content += "<br><label for=\"password\">Password: </label>";
  content += String("") + "<input type=\"password\" id=\"password\" name=\"password\" value = \"" + "" + "\"><br><br>";

  content += "<input type=\"submit\" value=\"Update\">";
  
  content += "</form>";



  content += "</div>"; 
  content += "</body>"; 

   CElectronics::m_server.send( 200, "text/html", content);
}


// *******************************************************************************
// CMotionDetector
// Electronics-With-Bricks assembly set Motion Detector
// *******************************************************************************

class CMotionDetector : public CElectronics
{
public:
  CMotionDetector( char* szVersion, int gpioDetect = D2 );

  virtual void setup();
  virtual void loop();

  static void webpageHome();
  static void webpageRun();

public:
  static bool m_bMotionDetected;

private:
  int m_gpioDetect;
  int m_nDetectTicks; // millis() when the last motion was detected
  static const int m_nHoldTicks = 5000; // # of milliseconds a detected movement will be stored
};

bool CMotionDetector::m_bMotionDetected = false;



CMotionDetector::CMotionDetector( char* szVersion, int gpioDetect ) : CElectronics( "Motion Detector", szVersion )
{
  m_gpioDetect = gpioDetect;
  m_nDetectTicks = 0;
}

void CMotionDetector::setup()
{
  CElectronics::setup();

  m_server.on( "/", webpageHome );
  m_server.on( "/run", webpageRun );

  pinMode( m_gpioDetect, INPUT );
}

void CMotionDetector::loop()
{
  CElectronics::loop();

  int nDetect = digitalRead( m_gpioDetect );
  if( nDetect == HIGH )
  {
    m_bMotionDetected = true; // Reset of bDetect is done after reported once via html
    m_nDetectTicks = millis();
  }
  else
  {
    int nTicks = millis();
    if( nTicks > m_nDetectTicks + m_nHoldTicks )
      m_bMotionDetected = false;
  }

//  Serial.printf( "nDetect = %d\n", nDetect );
}

void CMotionDetector::webpageHome()
{
  webpageInfo();
}

void CMotionDetector::webpageRun()
{
  String content = "";
  content += "<!DOCTYPE HTML>";
  content += "<html>"; 

  content += "<head>"; 
  content += "<meta http-equiv=\"refresh\" content=\"1\">"; 
  content += "<style>"; 
  content += ".wrapper {max-width:90%;margin:0 auto;text-align:center;}"; 
  content += ".btn {margin:15px;}";   
  if( CMotionDetector::m_bMotionDetected )
  {
    content += "body{background-color:#ff0000;}";   
//    CMotionDetector::m_bMotionDetected = false;
  }
  content += "</style>";
  content += "<script>window.focus();</script>";
  content += "</head>"; 

  content += "<body>"; 
  content += "<div class='wrapper'>"; 
  content += "<h2>Electronics-With-Bricks</h2>"; 
  content += "<br>Assembly Set = Motion Detector"; 
  content += "<br>Version = " + String(VERSION) + ""; 
  content += "<br/><br/>"; 
  content += "</div>"; 

  content += "<div>"; 
  content += "<form action=\"/\">";

  content += "</form>";
  content += "</div>"; 

  content += "</body>";
  content += "</html>"; 

   CMotionDetector::m_server.send( 200, "text/html", content);
}



// *******************************************************************************
// Program
// *******************************************************************************

CMotionDetector motionDetector( VERSION, D2 );

void setup()
{
  Serial.begin(9600);
  delay(5000);

  int err = LittleFS.begin();
  Serial.printf( "LittleFS.begin returned %d\n", err );

  motionDetector.setup();
}

void loop()
{
  motionDetector.loop();

  delay( 100 );
}

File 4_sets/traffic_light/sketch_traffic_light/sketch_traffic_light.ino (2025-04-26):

// The GPIO pins controlling the lights of the traffic light, HIGH:illuminated, LOW=off)
#define GPIO_RED      D7
#define GPIO_YELLOW   D6
#define GPIO_GREEN    D5

// The GPIO pins controlling the led's on the control table
// The two gpio's set up a radio button (i.e. exactly one of them activated (=HIGH) at a time)
#define GPIO_SERVICE    D1
#define GPIO_AUTOMATIC  D2
#define GPIO_OFF        D3 // not available yet

// Handling of the controltable which acts as a radio button
// CRadioButton is just designed for our hardware, not as a reusable class (uses the above GPIO defines)
class CRadioButton
{
public:
  CRadioButton();

  int Check();
  void Set( int newPort );

private:
  int m_nPort; // Currently selected port
};

// Handling of the traffic light lamps.
// CTrafficLight is just designed for our hardware, not as a reusable class (uses the above GPIO defines)
class CTrafficLight
{
public:
  // The enum value equals the gpio of the radio button activating the mode
  typedef enum Mode_t
  {
    eMode_off       = 0,
    eMode_service   = 1,
    eMode_automatic = 2,
  }
  Mode_t;

  // The state of the traffic light lamps during automatic mode
  typedef enum State_t
  {
    eState_red,
    eState_yellow,
    eState_green,
    eState_yellowred,
  }
  State_t;

public:
  CTrafficLight();

  void SetMode( Mode_t enu );   // Change the behaviour of the traffic light behaviour according to the newly selected mode
  void Update();                // Drive the traffic light lamps according the current mode and (in automatic mode) according to the current m_enuTrafficLightAutomaticState
  void Loop();                  // The regular loop calls this function in order to drive the periodic switching of the traffic light lamps (dependant of the current mode)

private:
  Mode_t  m_enuMode;
  State_t m_enuState;           // Used in automatic mode
  bool m_bServiceBlink;         // Used in service mode (true when the yellow led is currently on)
  int m_nLastTick;              // Used for timing of the lamps. Holds milliseconds (= return of millis()) since last time the lamps were adjusted
};


CRadioButton radioButton;
CTrafficLight trafficLight;

void setup() {
  // put your setup code here, to run once:

  radioButton.Set( GPIO_OFF );

  pinMode( GPIO_RED, OUTPUT );
  pinMode( GPIO_YELLOW, OUTPUT );
  pinMode( GPIO_GREEN, OUTPUT );

//  trafficLightSetMode( eTrafficLightMode_off );
  trafficLight.SetMode( CTrafficLight::eMode_off );
}

void loop()
{
  // Check the control table for a button press
  int port = radioButton.Check(); 

  // Was a mode change requested?
  if( port >= 0 )
  {
    // Yes, port >= 0 means: a mode change was requested

    // Use this control table selection as current one and drive the corresponding control table led
    radioButton.Set( port );

    // Match the radio button port to the requested traffic light mode
    CTrafficLight::Mode_t requestedTrafficLightMode = CTrafficLight::eMode_off;
    switch( port )
    {
      default: // The default case is an error condition here and should not occur
      case GPIO_SERVICE:
        requestedTrafficLightMode = CTrafficLight::eMode_service;
        break;
      case GPIO_AUTOMATIC:
        requestedTrafficLightMode = CTrafficLight::eMode_automatic;
        break;
    }

    // Switch the traffic light to the newly selected mode
    trafficLight.SetMode( requestedTrafficLightMode );
  }

  // Regularily hand over control to the traffic light, so that it can handle the switching of the traffic light lamps over time
  trafficLight.Loop();
}


// ****************************************************************************************
// Implementation CRadioButton
// ****************************************************************************************

CRadioButton::CRadioButton()
{
  m_nPort = GPIO_OFF;
}

int CRadioButton::Check()
{
  int newPort = -1;

  if( m_nPort != GPIO_AUTOMATIC // This means we are not in AUTOMATIC mode and therefore GPIO_AUTOMATIC is currently INPUT and can be read
    && digitalRead(GPIO_AUTOMATIC) == HIGH  ) // This means: the push button on GPIO_AUTOMATIC is currently pressed
  {
    newPort = GPIO_AUTOMATIC; // We detected that AUTOMATIC mode is requested
  }
  else if( m_nPort != GPIO_SERVICE // This means we are not in SERVICE mode and therfore GPIO_SERVICE is currently INPUT and can be read
    && digitalRead(GPIO_SERVICE) == HIGH ) // This means: the push button on GPIO_SERVICE is currently pressed
  {
     newPort = GPIO_SERVICE; // We detected that SERVICE mode is requested
  }

  return newPort;
}

void CRadioButton::Set( int newPort )
{
  if( newPort >= 0 )
  {
    m_nPort = newPort;
    pinMode( GPIO_AUTOMATIC, (m_nPort==GPIO_AUTOMATIC) ? OUTPUT : INPUT );
    pinMode( GPIO_SERVICE, (m_nPort==GPIO_SERVICE) ? OUTPUT : INPUT );
    digitalWrite( m_nPort, HIGH );
  }
}


// ****************************************************************************************
// Implementation CTrafficLight
// ****************************************************************************************

CTrafficLight::CTrafficLight()
{
  m_enuMode = eMode_off;
  m_enuState = eState_red;
  m_bServiceBlink = false;
  m_nLastTick = 0;
}

// Change the behaviour of the traffic light behaviour according to the newly selected mode
void CTrafficLight::SetMode( Mode_t enu )
{
  m_enuMode = enu;
  m_enuState = eState_red;
  m_bServiceBlink = false;
  m_nLastTick = millis(); // This means: The traffic light lamp state has just been updated

  Update();
}

void CTrafficLight::Update()
{
  switch( m_enuMode )
  {
    case eMode_off:
      digitalWrite( GPIO_RED, LOW );
      digitalWrite( GPIO_YELLOW, LOW );
      digitalWrite( GPIO_GREEN, LOW );
      break;
    case eMode_service:
      digitalWrite( GPIO_RED, LOW );
      digitalWrite( GPIO_YELLOW, HIGH );
      digitalWrite( GPIO_YELLOW, m_bServiceBlink ? HIGH : LOW );
      digitalWrite( GPIO_GREEN, LOW );
      break;
    case eMode_automatic:
      switch( m_enuState )
      {
        case eState_red:
          digitalWrite( GPIO_RED, HIGH );
          digitalWrite( GPIO_YELLOW, LOW );
          digitalWrite( GPIO_GREEN, LOW );
          break;
        case eState_yellow:
          digitalWrite( GPIO_RED, LOW );
          digitalWrite( GPIO_YELLOW, HIGH );
          digitalWrite( GPIO_GREEN, LOW );
          break;
        case eState_green:
          digitalWrite( GPIO_RED, LOW );
          digitalWrite( GPIO_YELLOW, LOW );
          digitalWrite( GPIO_GREEN, HIGH );
          break;
        case eState_yellowred:
          digitalWrite( GPIO_RED, HIGH );
          digitalWrite( GPIO_YELLOW, HIGH );
          digitalWrite( GPIO_GREEN, LOW );
          break;
      }
      break;
  }
}
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

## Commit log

2025-04-21 assembly_set traffic_light Readme.pdf added
2025-04-21 assembly_sets traffic_light and dice added
2025-04-22 ino files for assembly sets dice and traffic_light
2025-04-26 assembly set traffic light improved (circuit design, programming)
2025-05-22 added assembly set motion sensor
2025-05-23 Restructured, some stl resources added
    [body_1x1_wire.stl, body_2x1_wire.stl, body_2x2_crossing.stl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]
2025-05-23 added some board resources (gerber)
2025-05-23 assembly set dice updated
2025-06-11 Added sketch lab power supply
2026-05-03 sequence of directories modified and projects directory added
    [body_1x1_wire.stl, body_2x1_wire.stl, body_2x2_crossing.stl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]
2026-08-30 8mm studded bases plate
2026-10-07 new brick version
    [body_1x1_wire.stl, body_2x1_wire.stl, body_2x2_crossing.stl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]
2026-10-09 added resources
    [body_1x1.stl, body_2x1.stl, body_2x2.stl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]
2026-10-15 Added BOM TryIt
2026-10-15 minor fixes BOM TryIt
2026-10-22 added amplifier LM386 housing
2026-10-22 added gerber for basic1 and basic2 boards
